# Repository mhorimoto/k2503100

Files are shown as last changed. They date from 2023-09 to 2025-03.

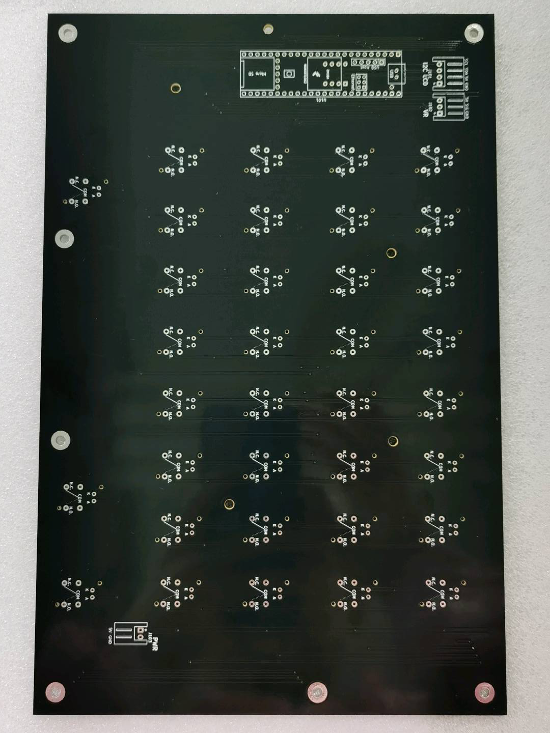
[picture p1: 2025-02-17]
DOCS/workarea/S-B67819ASP32サンプル写真確認/1.jpg

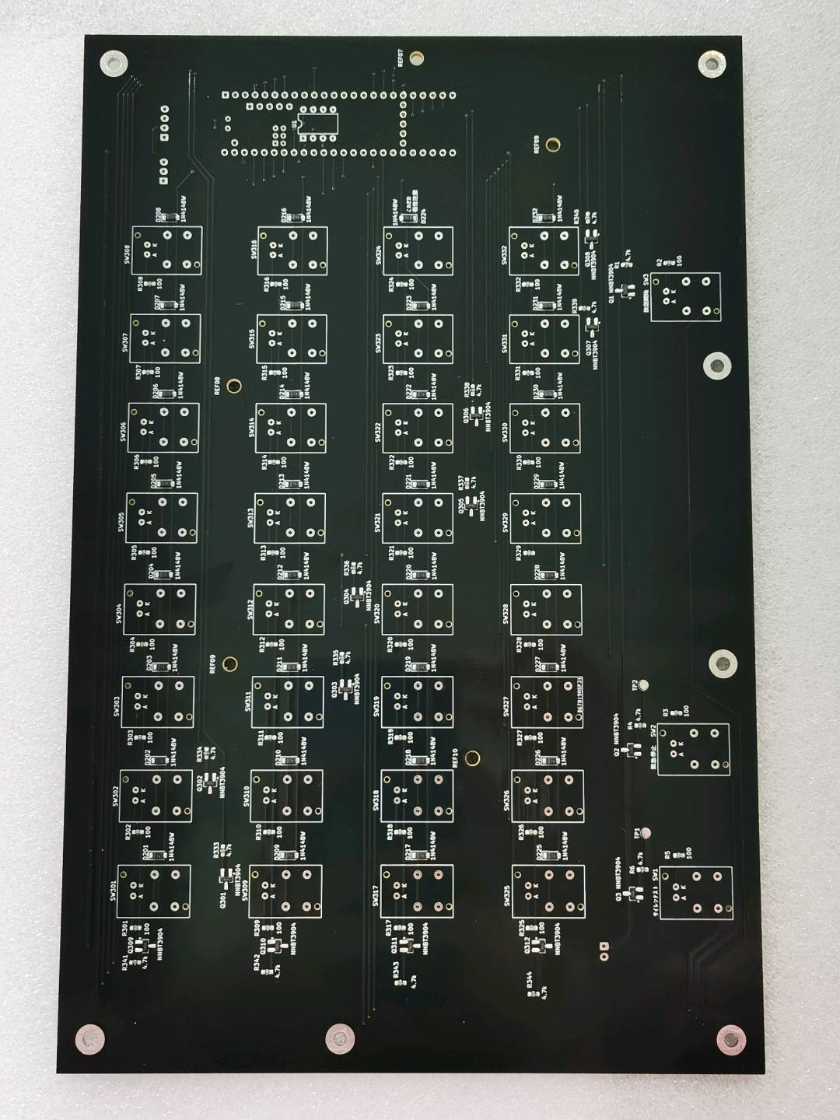
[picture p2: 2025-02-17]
DOCS/workarea/S-B67819ASP32サンプル写真確認/3.jpg

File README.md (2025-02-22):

# k2503100
リレーは使わない、SNMPだけ送信する＆Teensy4.1

## ディレクトリの説明

+ DOCS  
  設計に関する検討資料が含まれている。
+ KiCAD  
  KiCADによる回路設計の情報が含まれている。
  本装置はボタンスイッチを配置した基板が本体ケースの構成要素として大きな位置づけなので、
  本体ケースの製作に要する寸法図データもこのディレクトリに含めている。
+ PARTS_SPEC  
  製作に使用した部品の個別の仕様書やカタログが含まれている。
+ main  
  プログラムのソースコードが収められている。
  コンパイルなどはplatformIOを用いている。
+ snmp-manager  
  snmp-managerライブラリを用いた試験プログラムが収められている。普通は使わない。
+ snmp-test  
  snmp動作のテストプログラムが収められている。普通は使わない。
+ snmplib  
  snmpsetの動作確認用のプログラムが収められている。普通は使わない。
+ tools
  Ubuntu(Debian)系でplatformIOを使うときのudevruleファイルが収められている。

# CAUTION VERY IMPORTANT 重要な注意

PCB Revision 1.20まではLEDドライブ用のTrのフットパターンを間違えているので使わないように。

Don't use the wrong foot pattern of Tr for LED drive until PCB Revision 1.20.

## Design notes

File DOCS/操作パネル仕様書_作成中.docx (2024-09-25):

機器仕様書(暫定)

操作パネル

# 1. 適用

本仕様書は操作パネル（型式をここに入れる）に適用します。

# 2. 概要

本機は、事務机などのデスクの上に設置するBOX型の装置です。

BOXにはボタンが搭載されており、ボタンを押下することにより、FM告知放送システム、

メール発報システムを自動で起動させることが出来ます。

# 3. 特徴

本機は以下の特長を持ちます。

・ボタンを35個搭載しており、それぞれ、地区ボタン（32地区）、テストサイレンボタン、

強制終了ボタン、放送開始ボタンを有しております。

・選択されたボタンは選択されたことが分かるように点灯します。

・地区ボタンを選択し、放送開始ボタンを押下することにより、その地区に対応したFM告知放

送と、消防関係者へのメールを発報することが出来ます。

・地区選択を誤った場合、再度ボタンを押下することにより、選択解除が出来ます。

・地区選択後、放送開始ボタンを1分間押下されなかった場合、全ての条件を解除します。

（誤放送防止）

・放送開始後に、誤放送に気付いた場合、強制終了ボタンを押す事により、放送を中止すること

が出来ます。

# 4. 機器仕様

## 性能（暫定）

CPU | Intel® Xeon® E-2124（3.3GHz 4コア）
メモリ | 16GB DDR4 UDIMM
ストレージ | 2TB ホットプラグ3.5型SAS HDD×2（同一HDD 2基でRAID1構成）
LANインターフェース | RJ-45コネクタ×4（Ethernet® 1Gb 4ポート）
通信方式 | SNMP
電源 | AC100V (50/60 Hz)
消費電力 | 70VA
サイズ | W:434×D:424×H:44 mm（突起部除く）

## 環境条件（暫定）

本機は屋内専用です。動作環境は以下の通りとなりますが、日光の直射・結露・腐食性環境・衝撃・連続的な振動等は避けてください。

温度 | 動作時 10～35℃
湿度 | 動作時 8～90%（結露しないこと）

# 5. 外形図（暫定）

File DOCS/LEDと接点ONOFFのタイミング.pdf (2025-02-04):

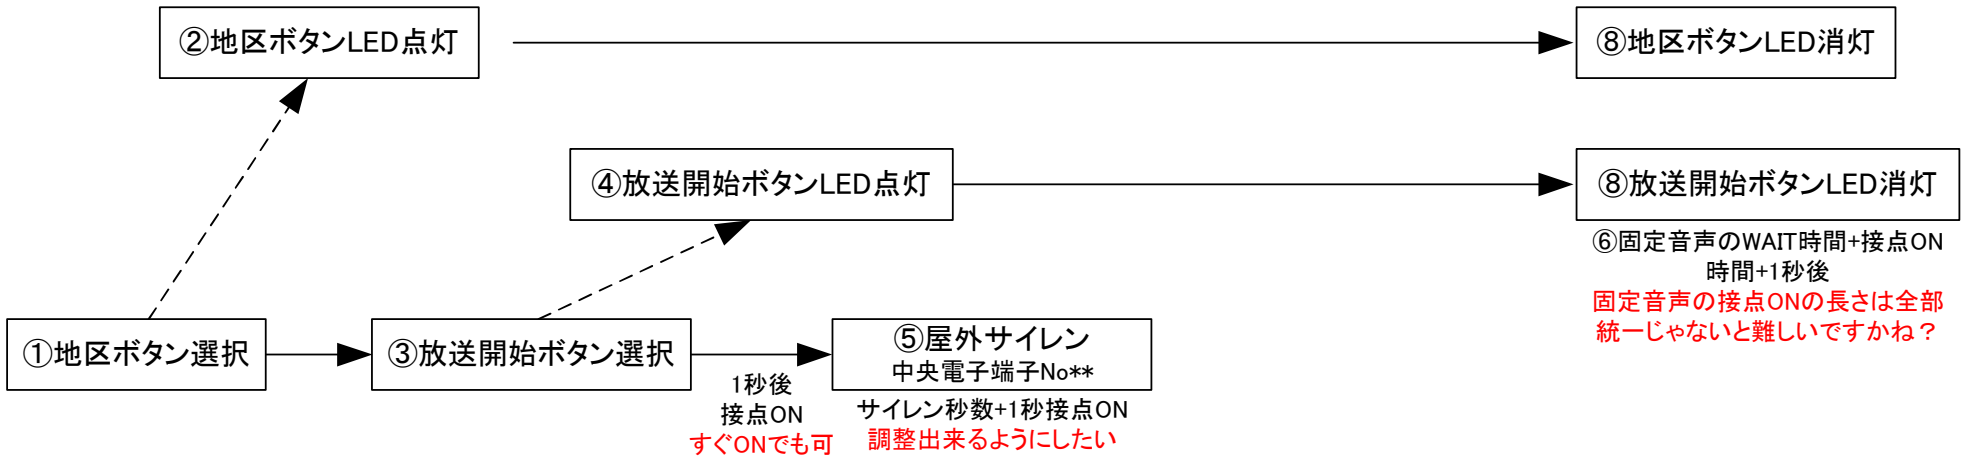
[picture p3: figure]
①地区ボタン選択; ③放送開始ボタン選択; ⑤屋外サイレン; 中央電子端子No**; サイレン秒数+1秒接点ON 調整出来るようにしたい; 1秒後 接点ON すぐONでも可; ②地区ボタンLED点灯; ④放送開始ボタンLED点灯; ⑧地区ボタンLED消灯; ⑧放送開始ボタンLED消灯; ⑥固定音声のWAIT時間+接点ON 時間+1秒後 固定音声の接点ONの長さは全部 統一じゃないと難しいですかね？

### ⑦メール発報

中央電子端子No**
接点3秒間ON
基本3秒で問題ないと思う
が、調整出来るようになって
いるとありがたいです

1秒+サイレン秒数+1秒後　接点ON
難しければ⑤と同時にONでも可

### ⑥固定音声ON

中央電子端子No**
地区名によって若干長さが変わる
接点ONの時間を現地で調整出来
るようにしたい

1秒+サイレン秒数+1秒後　接点ON
難しければ⑤と同時にONでも可

※当初はすぐに接点ONにする感じでしたが、
強制終了の対象に出来ると思い希望を書きました

# LED、接点ONのタイミングと時間

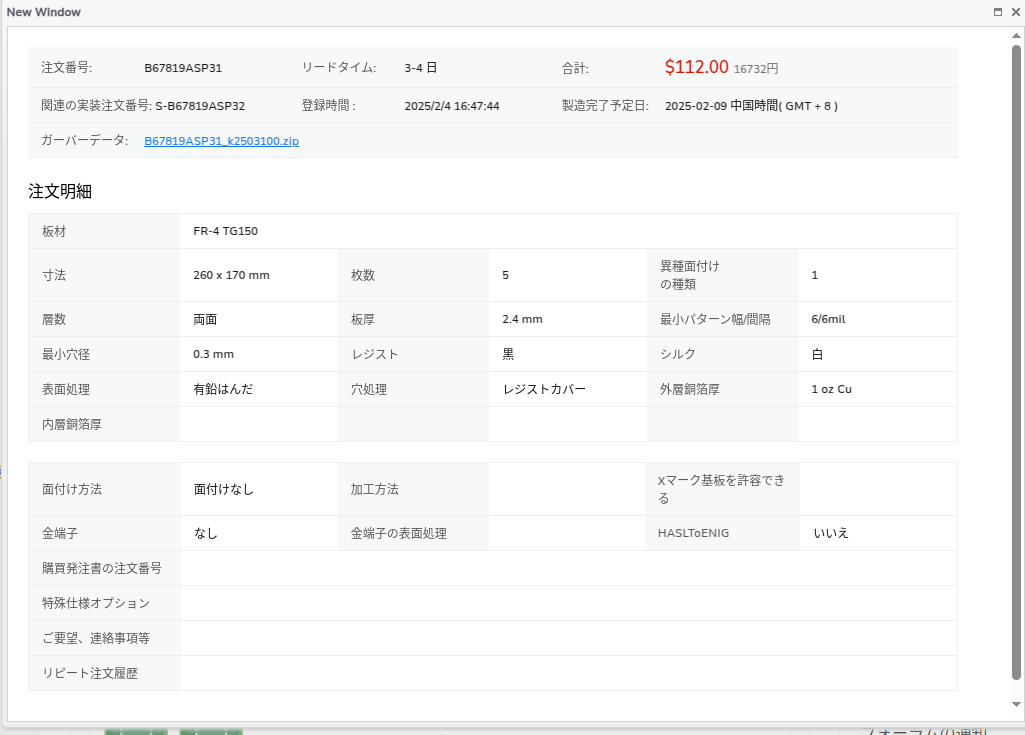
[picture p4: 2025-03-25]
KiCAD/k2503100/GOUT/Screenshot_PCBgogo.png

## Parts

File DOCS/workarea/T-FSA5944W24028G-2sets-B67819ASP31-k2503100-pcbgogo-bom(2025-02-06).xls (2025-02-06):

PCBGOGO Quotation, Order No.:
Item # | *Designator | *Qty | *Mfg Part # | Description / Value | *Package/Footprint | Your Instructions / Notes | *Delivery Time | *Actual Purchase Mfg Part # | *PCBGOGO Note | 客先確認
1 | R2,R3,R5,R301,R302,R303,R304,R305,R306,R307,R308,R309,R310,R311,R312,R313,R314,R315,R316,R317,R318,R319,R320,R321,R322,R323,R324,R325,R326,R327,R328,R329,R330,R331,R332 | 35 |  | 100『 』Resistor, US symbol | Resistor_SMD:R_0603_1608Metric_Pad0.98x0.95mm_HandSolder | ~ | ８日 | RC0603FR-07100RL |  | confirm OK
2 | R1,R4,R6,R333,R334,R335,R336,R337,R338,R339,R340,R341,R342,R343,R344 | 15 |  | 4.7k『 』Resistor, US symbol | Resistor_SMD:R_0603_1608Metric_Pad0.98x0.95mm_HandSolder | ~ | ８日 | RC0603FR-074K7L |  | confirm OK
3 | D201,D202,D203,D204,D205,D206,D207,D208,D209,D210,D211,D212,D213,D214,D215,D216,D217,D218,D219,D220,D221,D222,D223,D224,D225,D226,D227,D228,D229,D230,D231,D232 | 32 |  | 1N4148W『 』75V 0.15A Fast Switching Diode, SOD-123 | Diode_SMD:D_SOD-123 | https://www.vishay.com/docs/85748/1n4148w.pdf | ８日 | 1N4148W | The part we will supply is 1N4148W made by HXY MOSFET(华轩阳电子)，package: SOD-123 OK？ | HXY MOSFET 1N4148W is OK (https://www.lcsc.com/product-detail/Switching-Diode_HXY-MOSFET-1N4148W_C5345962.html)
4 | Q1,Q2,Q3,Q301,Q302,Q303,Q304,Q305,Q306,Q307,Q308,Q309,Q310,Q311,Q312 | 15 |  | NNBT3904『 』0.2A Ic, 40V Vce, Small Signal NPN Transistor | Package_TO_SOT_SMD:SOT-23_Handsoldering | https://akizukidenshi.com/goodsaffix/2N3904_MMBT3904_PZT3904.pdf | ８日 | MMBT3904 | The part we will supply is MMBT3904 made by HOTTECH，package: SOT-23 OK？ | HOTTECH MMBT3904 is OK (https://www.lcsc.com/product-detail/Bipolar-Transistors-BJT_Guangdong-Hottech-MMBT3904_C181119.html)
客户BOM中没有型号列，推荐了*Actual Purchase Mfg Part # *PCBWay Note请确认；麻烦客户下次提供有型号列和品牌列的BOM表

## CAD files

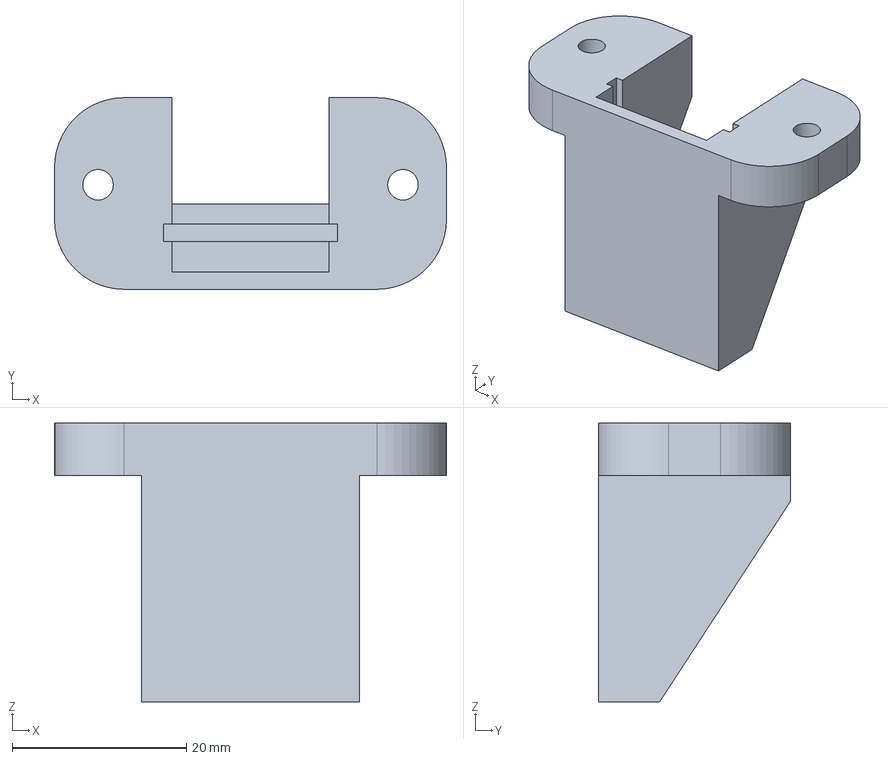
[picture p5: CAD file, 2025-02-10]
PARTS_SPEC/NIC-Adapter2-3views.FCStd
45.0 x 22.0 x 32.0 mm

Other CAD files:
PARTS_SPEC/NIC-Adapter2.FCStd
PARTS_SPEC/NIC-Adapter2.stl

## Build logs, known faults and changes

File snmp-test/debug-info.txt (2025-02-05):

14:41:39.178724 IP 192.168.42.32.snmp > atom3.55336:  C="private" GetResponse(36)  E:2589.1.2.2.2.6.1.5.112=1
	0x0000:  4500 0052 43da 0000 4011 612d c0a8 2a20  E..RC...@.a-..*.
	0x0010:  c0a8 2a23 00a1 d828 003e a3b5 3082 0032  ..*#...(.>..0..2
	0x0020:  0201 0004 0770 7269 7661 7465 a224 0204  .....private.$..
	0x0030:  0cf1 3aff 0201 0002 0100 3016 3014 060f  ..:.......0.0...
	0x0040:  2b06 0104 0194 1d01 0202 0206 0105 7002  +.............p.
	0x0050:  0101     
	
	3082 0032 0201 0004 0770 7269 7661 7465 a224 0204 0cf1 3aff 0201 0002 0100 3016 3014 060f 2b06 0104 0194 1d01 0202 0206 0105 7002 0101
	30 2F02 0100 0407 7072 6976 6174 65A3 2102 0101 0201 0002 0100 3000 1500 130F 2B06 0104 0194 1D01 0202 0206 0105 7002 0101
	
	Packet data: 0x30 0x2F 0x2 0x1 0x0 0x4 0x7 0x70 0x72 0x69 0x76 0x61 0x74 0x65 0xA3 0x21 0x2 0x1 0x1 0x2 0x1 0x0 0x2 0x1 0x0 0x30 0x0 0x15 0x0 0x13 0xF 0x2B 0x6 0x1 0x4 0x1 0x94 0x1D 0x1 0x2 0x2 0x2 0x6 0x1 0x5 0x70 0x2 0x1 0x1 
Packet size=49
Bytes sent: 49

15:30:58.779392 IP 192.168.42.35.37439 > 192.168.42.32.161:  C="private" SetRequest(36)  .1.3.6.1.4.1.2589.1.2.2.2.6.1.5.112=1
	0x0000:  4500 0050 26a8 4000 4011 3e61 c0a8 2a23  E..P&.@.@.>a..*#
	0x0010:  c0a8 2a20 923f 00a1 003c d5e1 3032 0201  ..*..?...<..02..
	0x0020:  0004 0770 7269 7661 7465 a324 0204 4ada  ...private.$..J.
	0x0030:  8966 0201 0002 0100 3016 3014 060f 2b06  .f......0.0...+.
	0x0040:  0104 0194 1d01 0202 0206 0105 7002 0101
	
3032 0201 0004 0770 7269 7661 7465 a324 0204 4ada 8966 0201 0002 0100 3016 3014 060f 2b06 0104 0194 1d01 0202 0206 0105 7002 0101 ==50bytes success
3082 0201 0004 0770 7269 7661 7465 A300 0204 2BB9 5130 0201 0002 0100 3010 300E 060F 2B06 0104 0194 1D01 0202 0206 0105 7002 0101
3082 0032 0201 0004 0770 7269 7661 7465 A300 0204 2BB9 5130 0201 0002 0100 3010 300E 060F 2B06 0104 0194 1D01 0202 0206 0105 7002 0101 AA
3032 0201 0004 0770 7269 7661 7465 A324 0204 42CE 0C1F 0201 0002 0100 3010 300E 060F 2B06 0104 0194 1D01 0202 0206 0105 7002 0100  BB
3032 0201 0004 0770 7269 7661 7465 A324 0204 ED3D 4074 0201 0002 0100 3016 3014 060F 2B06 0104 0194 1D01 0202 0206 0105 7002 0100  CC success
3032 0201 0004 0770 7269 7661 7465 A324 0204 FB5E B901 0201 0002 0100 3016 3014 060E 2B06 0104 0194 1D01 0202 0206 0105 7002 0101  -8 fail

Packet data: 3082 0032 0201 0004 0770 7269 7661 7465 A300 0204 2BB9 5130 0201 0002 0100 3010 300E 060F 2B06 0104 0194 1D01 0202 0206 0105 7002 0101 
Packet size=54
Bytes sent: 54

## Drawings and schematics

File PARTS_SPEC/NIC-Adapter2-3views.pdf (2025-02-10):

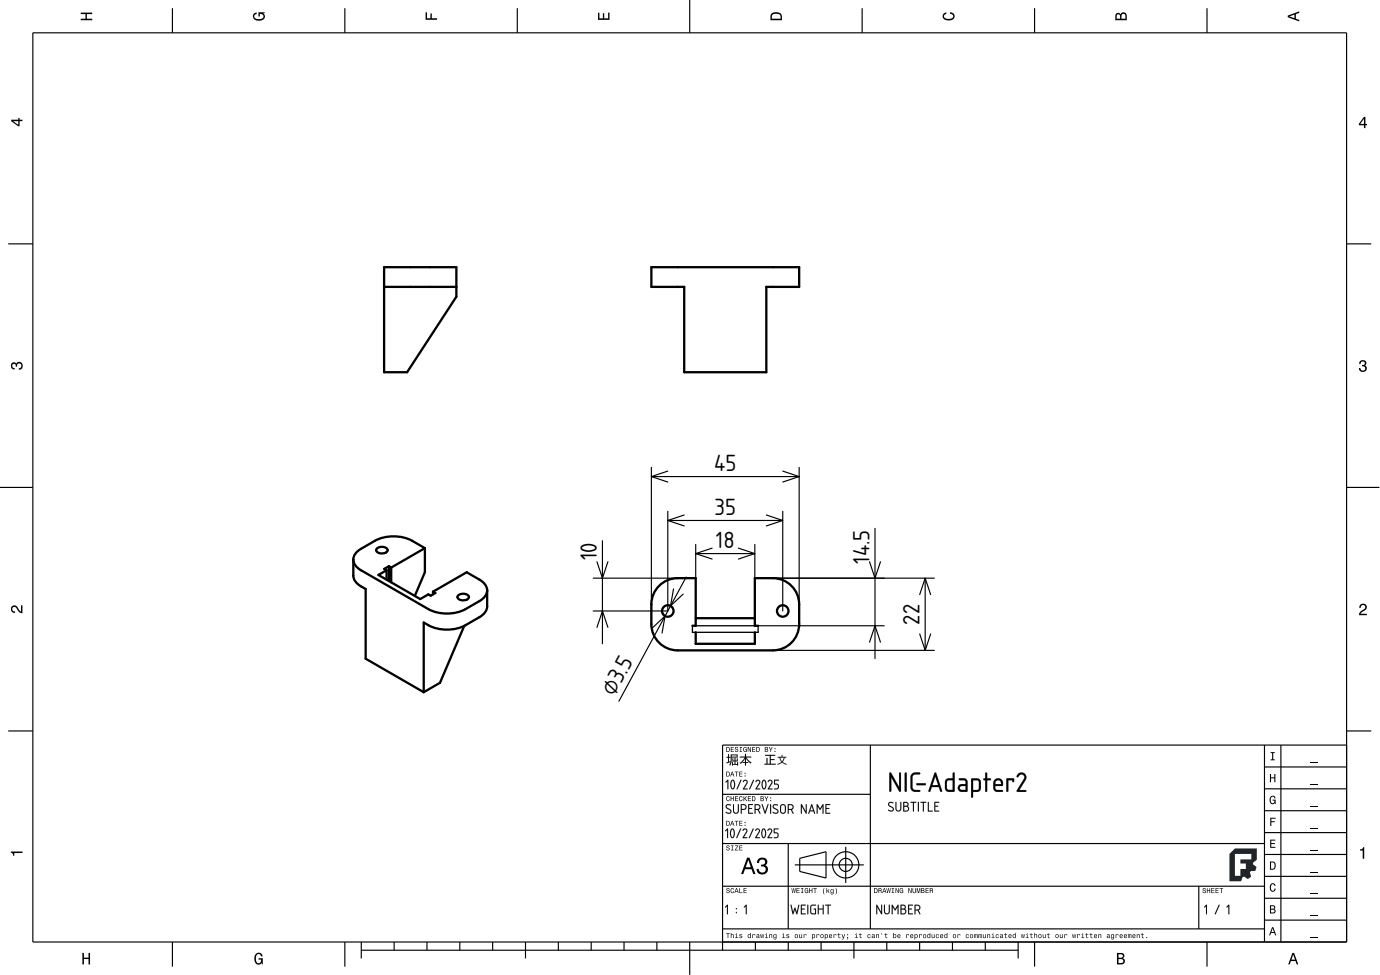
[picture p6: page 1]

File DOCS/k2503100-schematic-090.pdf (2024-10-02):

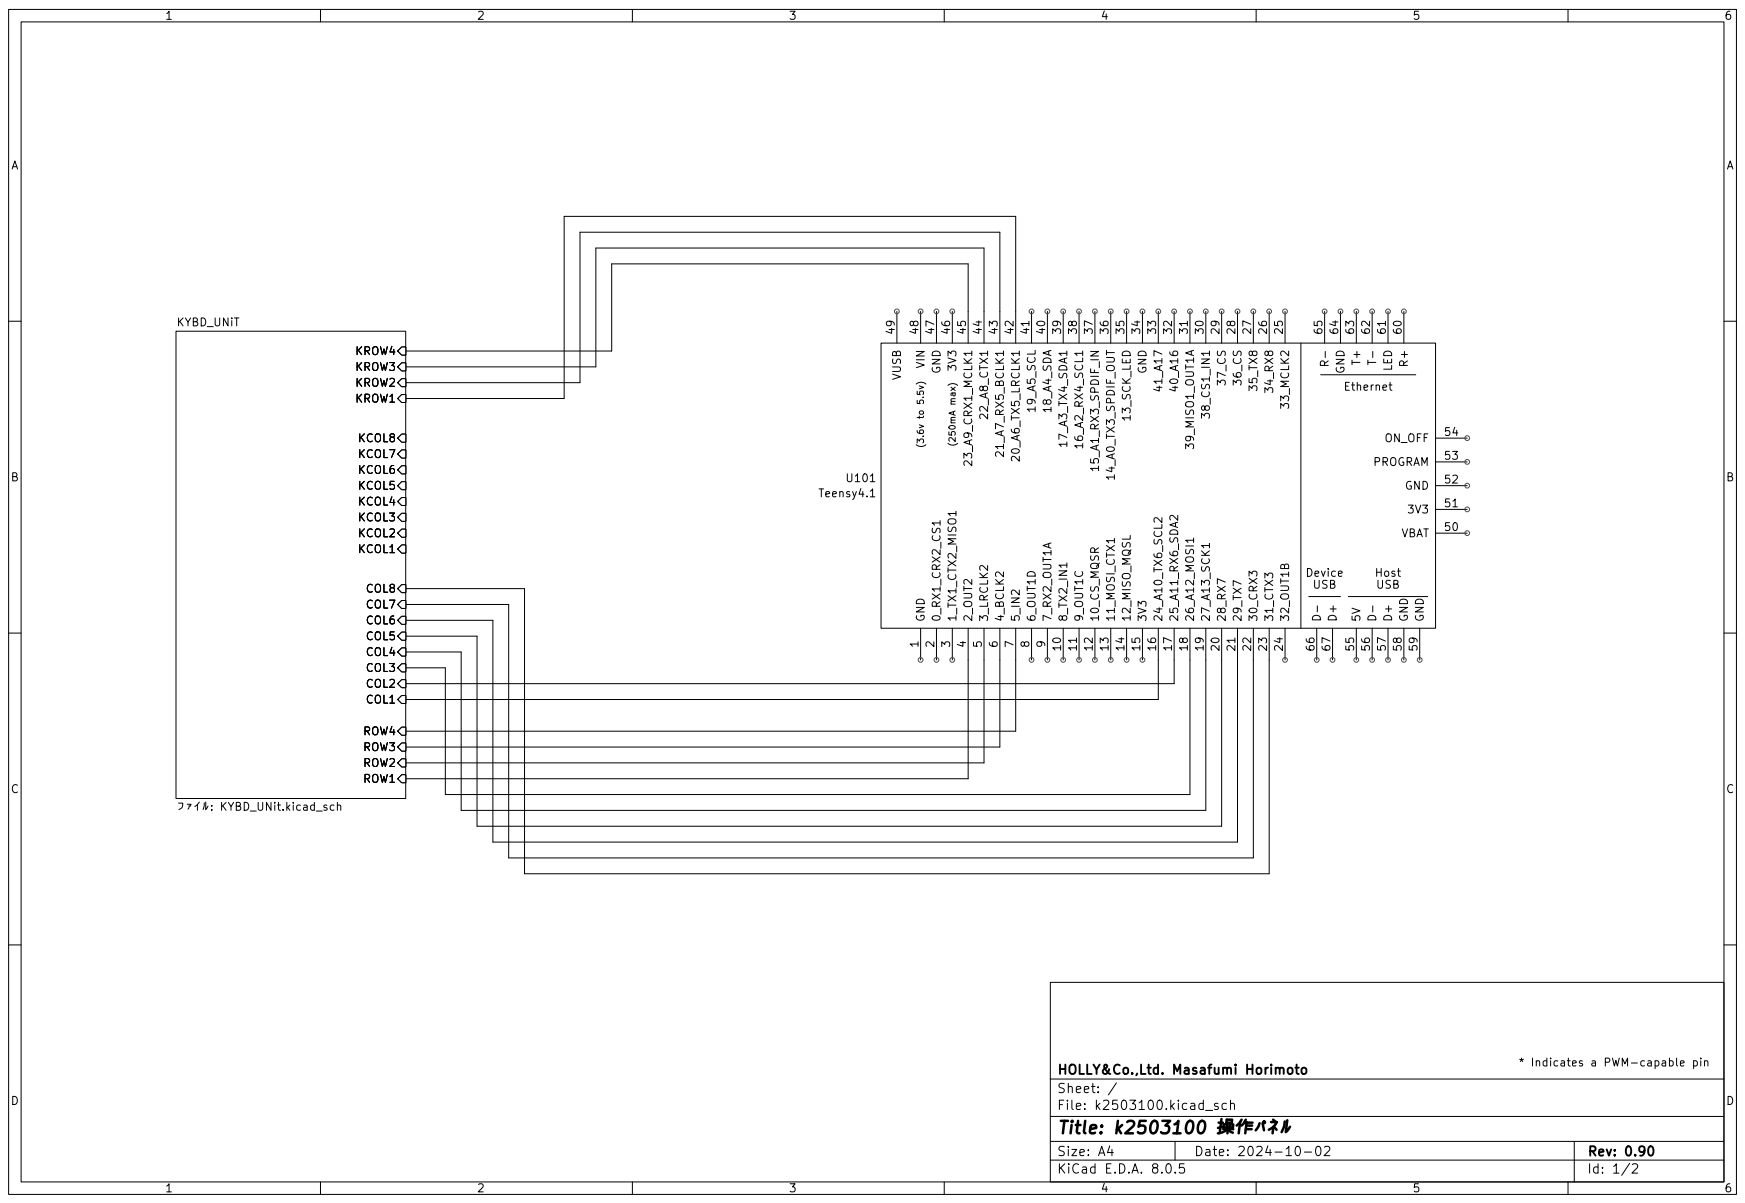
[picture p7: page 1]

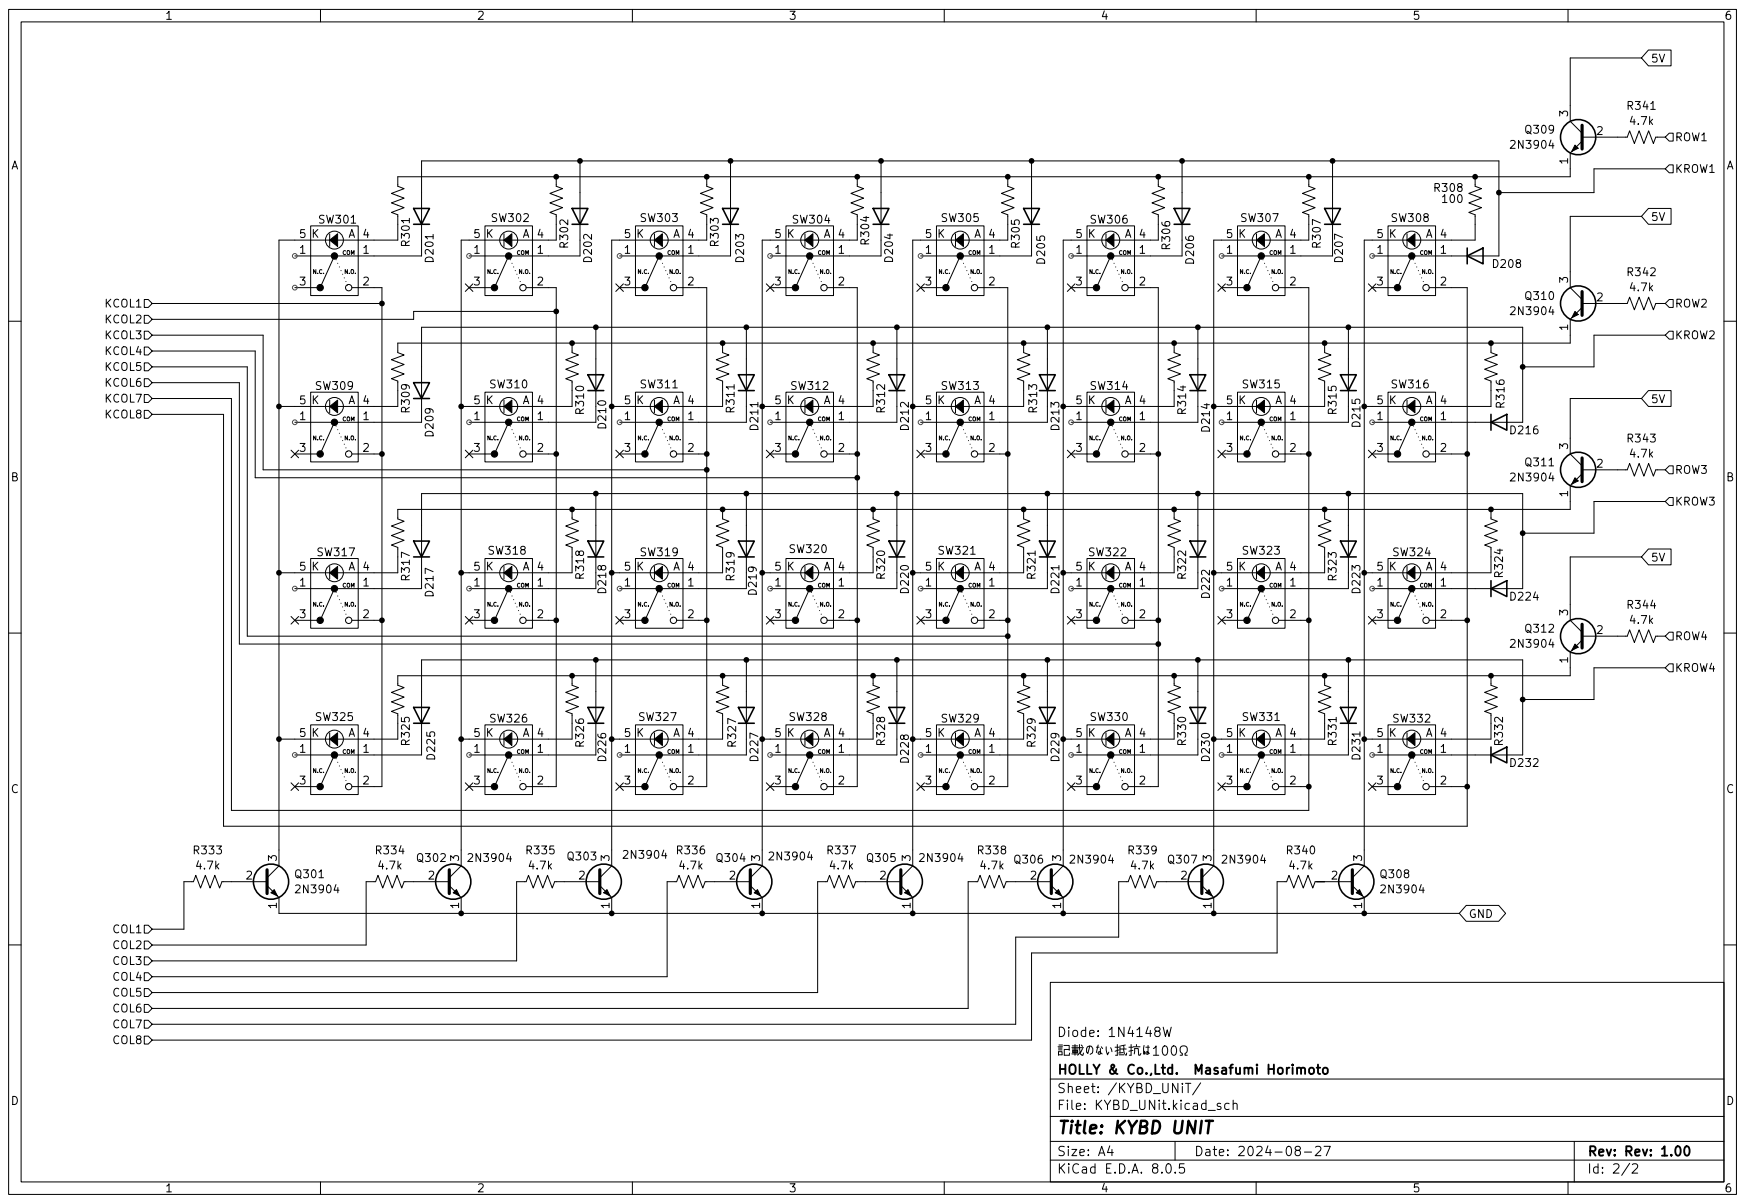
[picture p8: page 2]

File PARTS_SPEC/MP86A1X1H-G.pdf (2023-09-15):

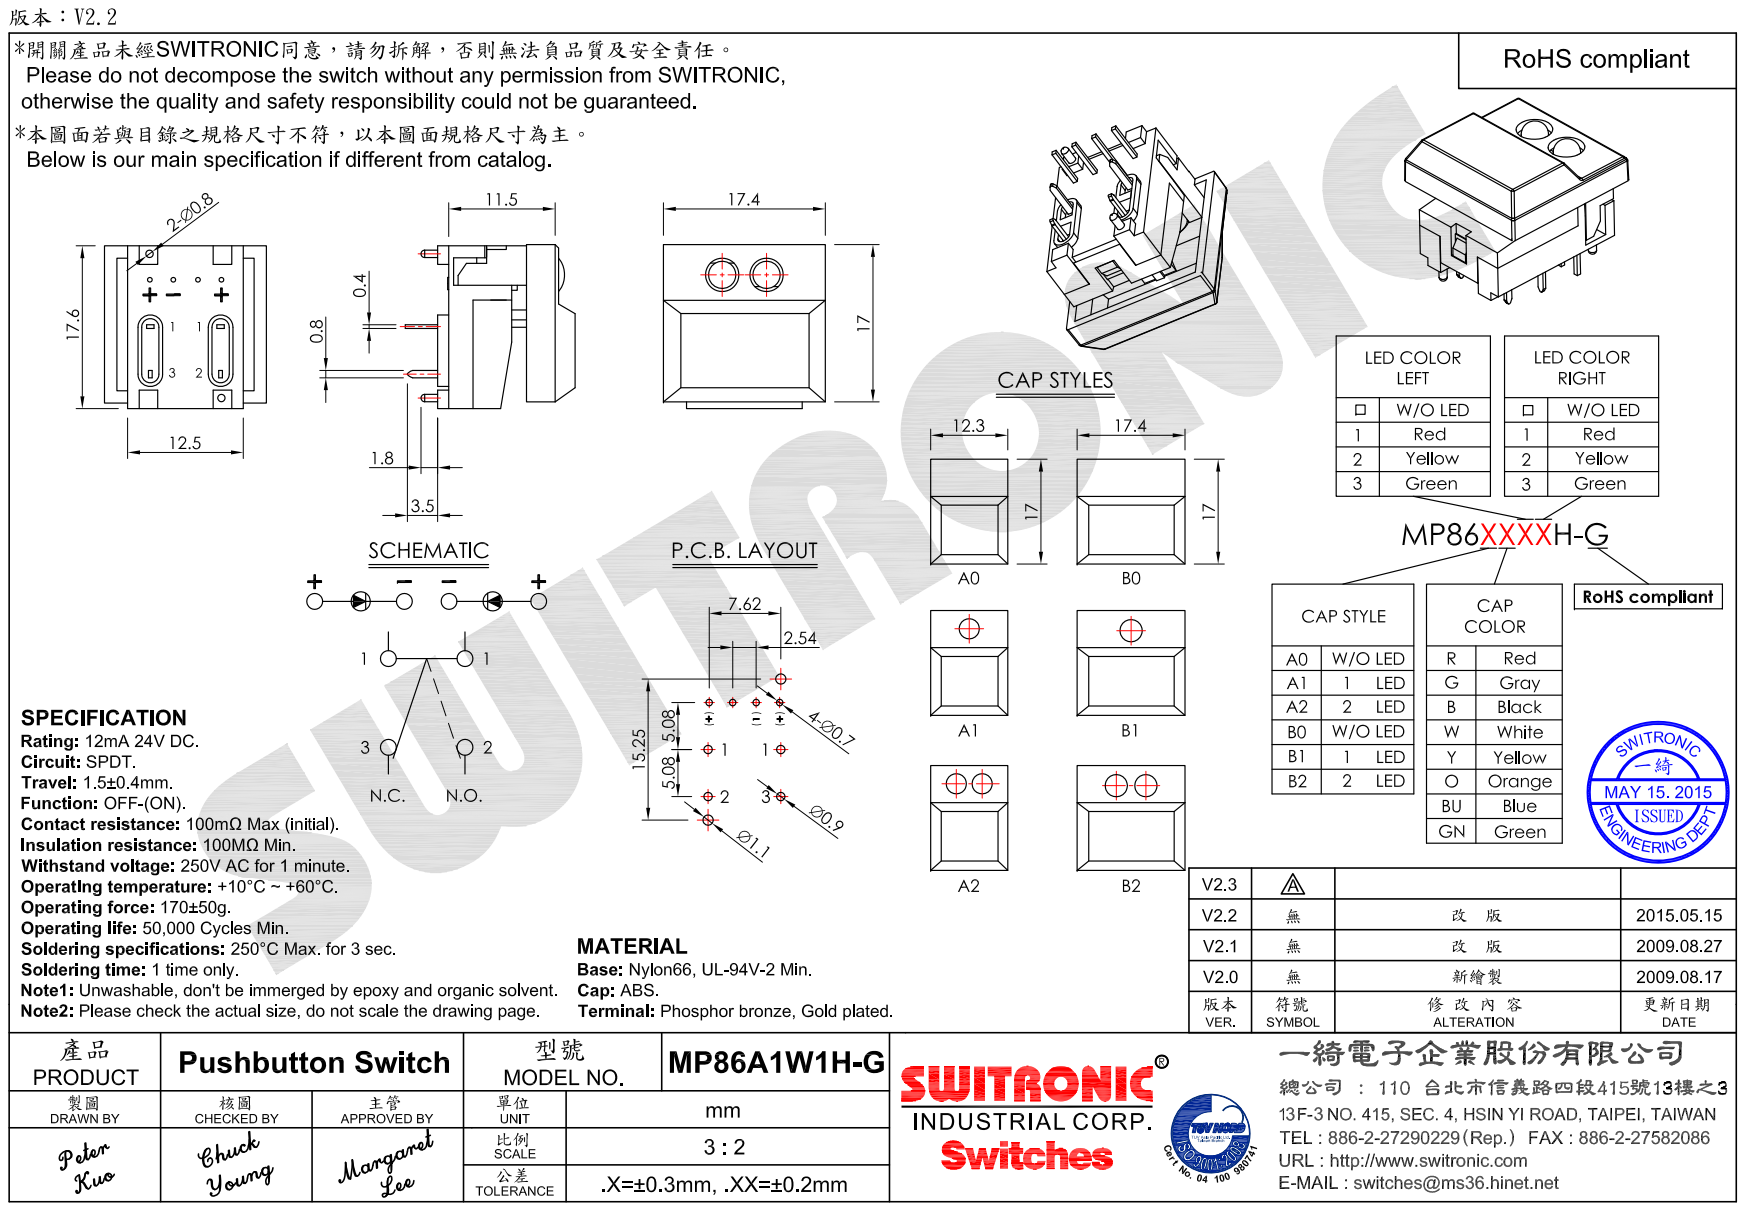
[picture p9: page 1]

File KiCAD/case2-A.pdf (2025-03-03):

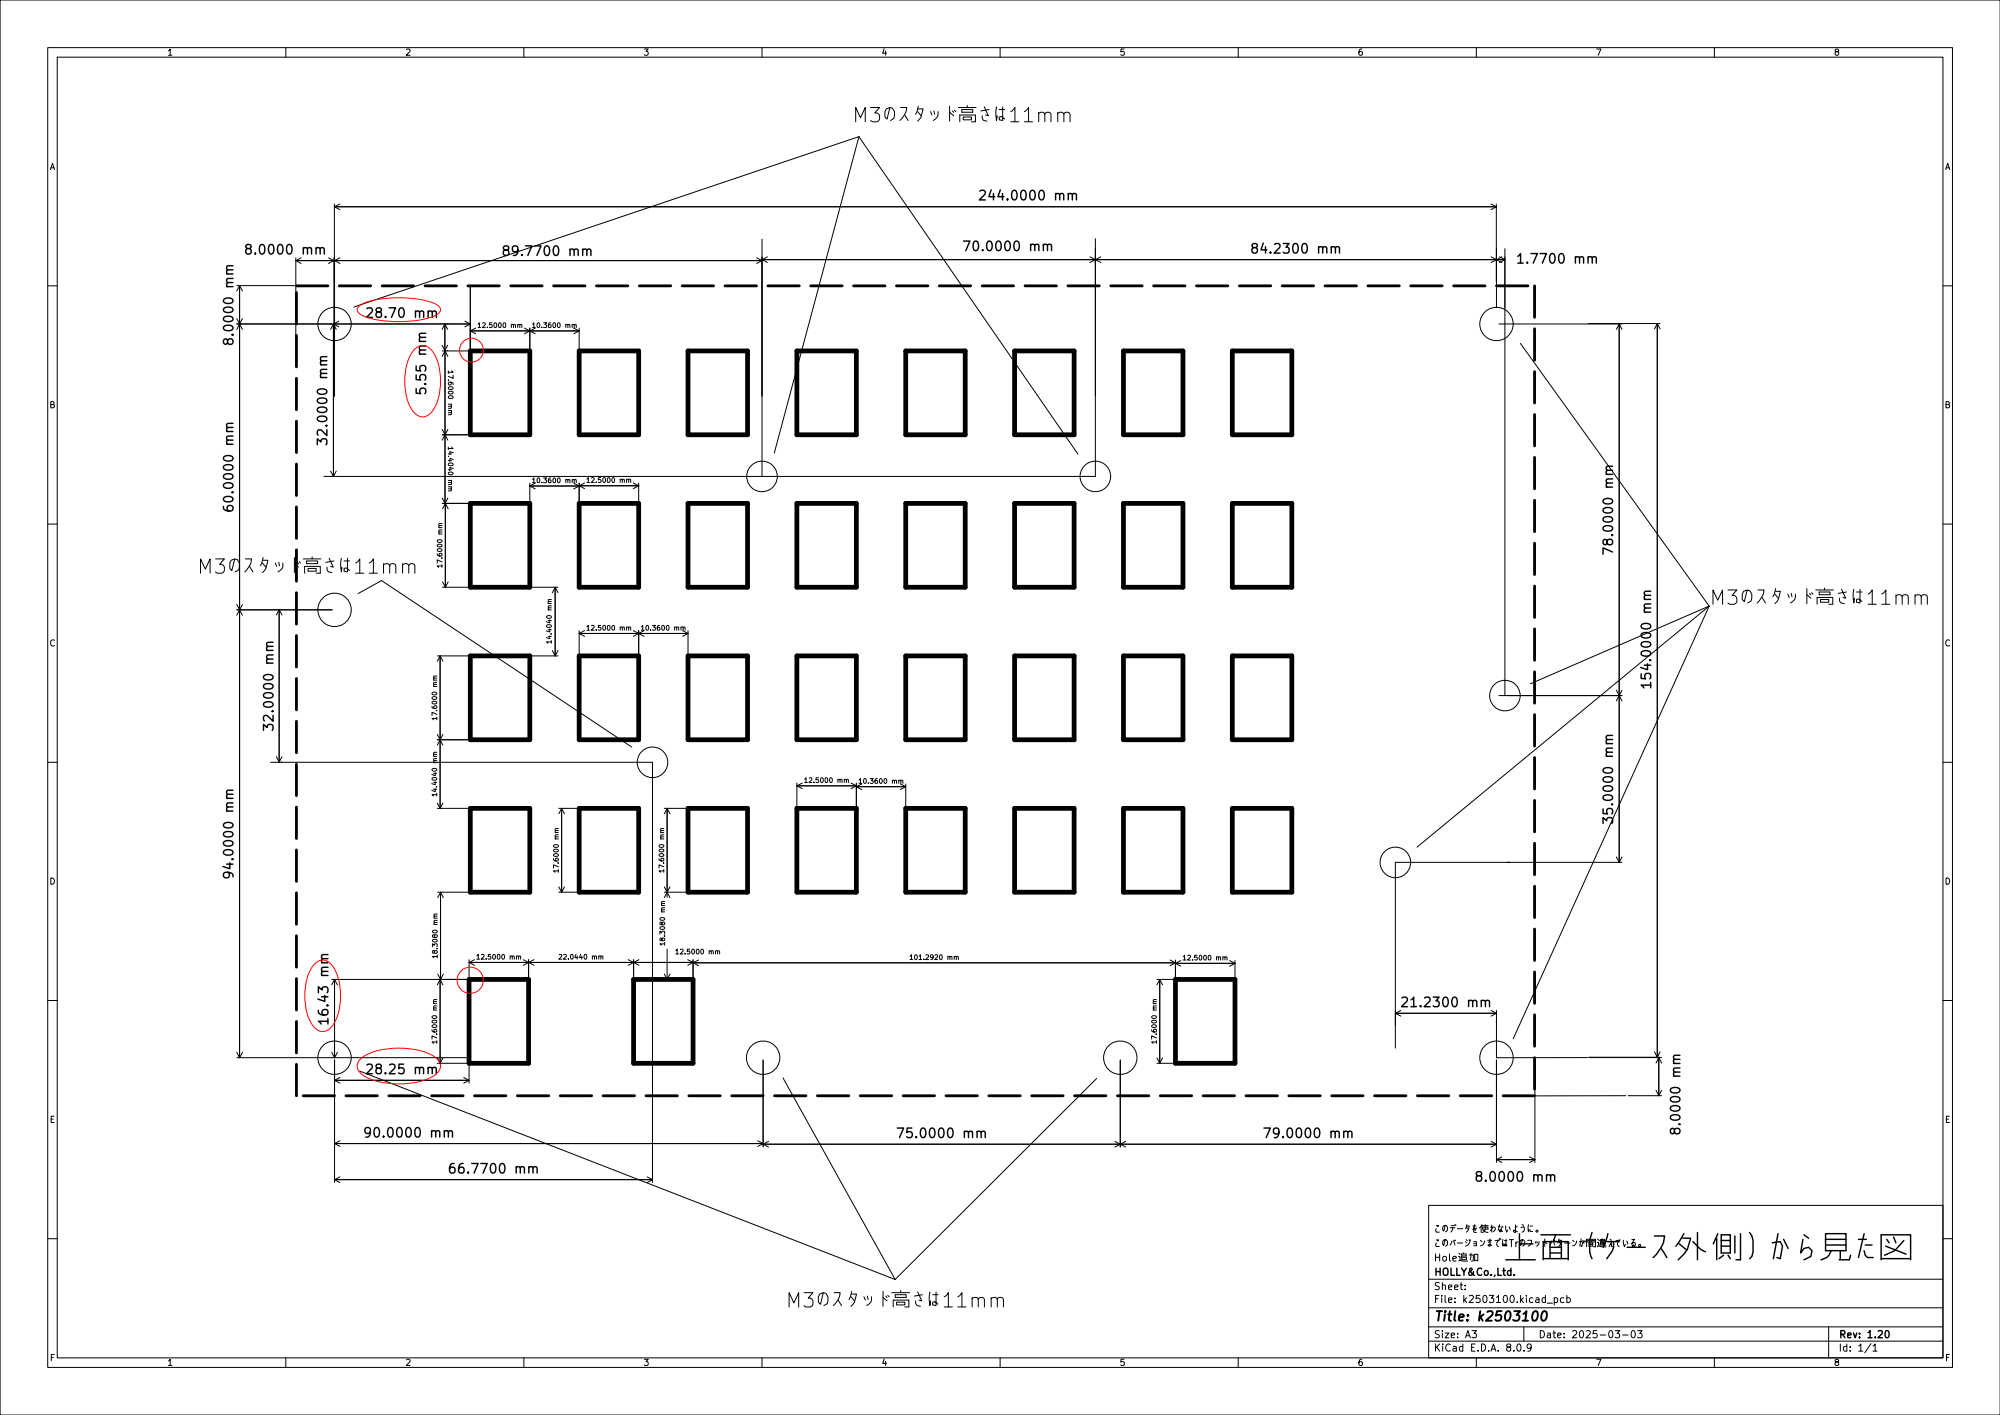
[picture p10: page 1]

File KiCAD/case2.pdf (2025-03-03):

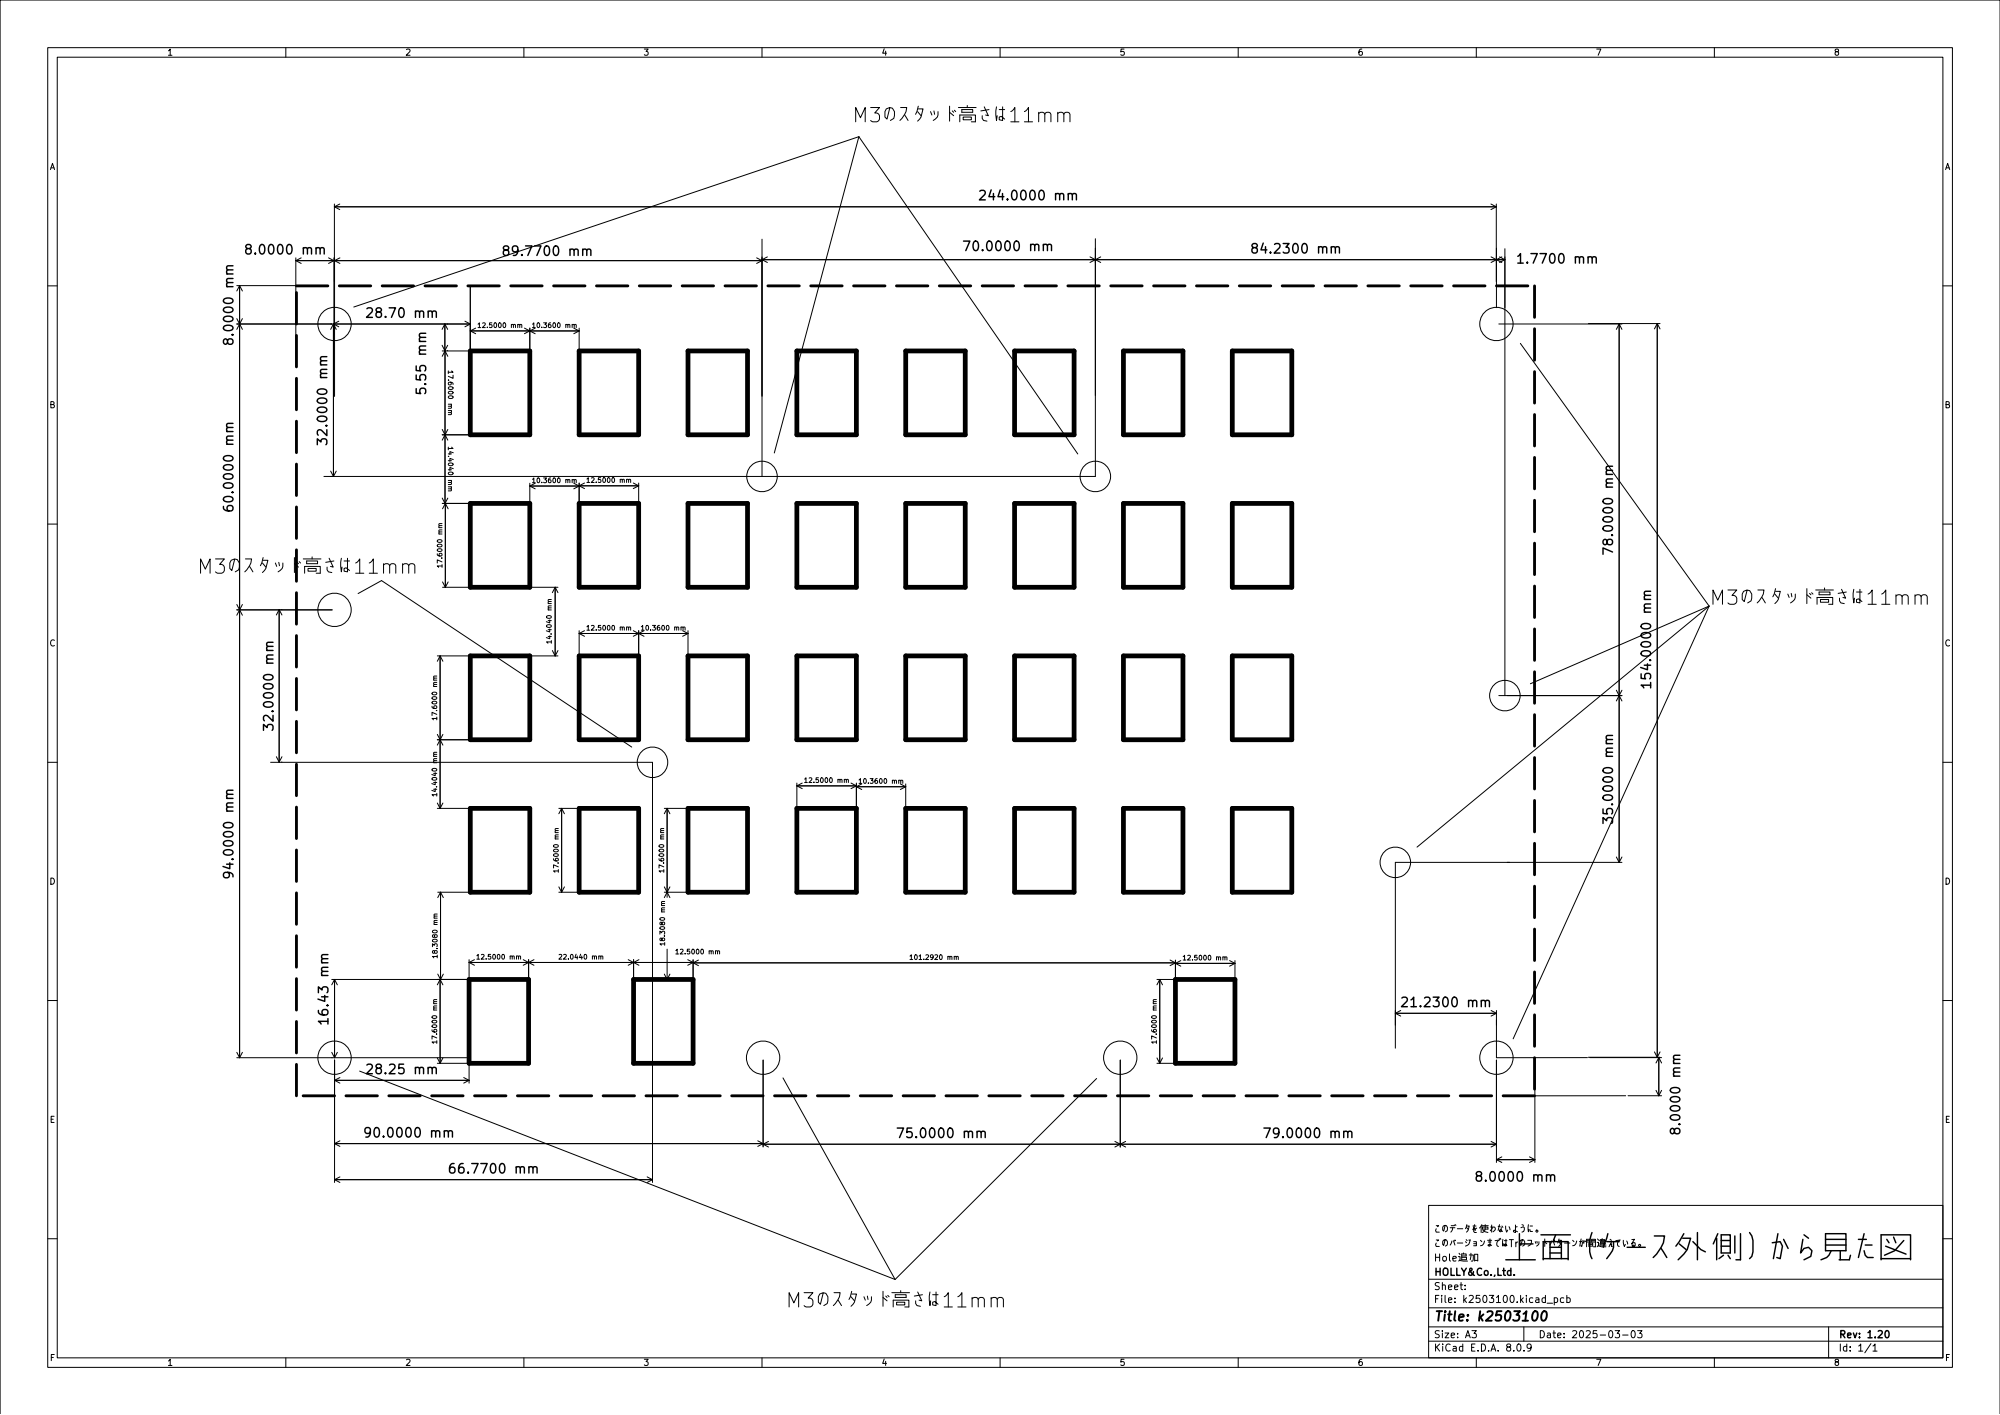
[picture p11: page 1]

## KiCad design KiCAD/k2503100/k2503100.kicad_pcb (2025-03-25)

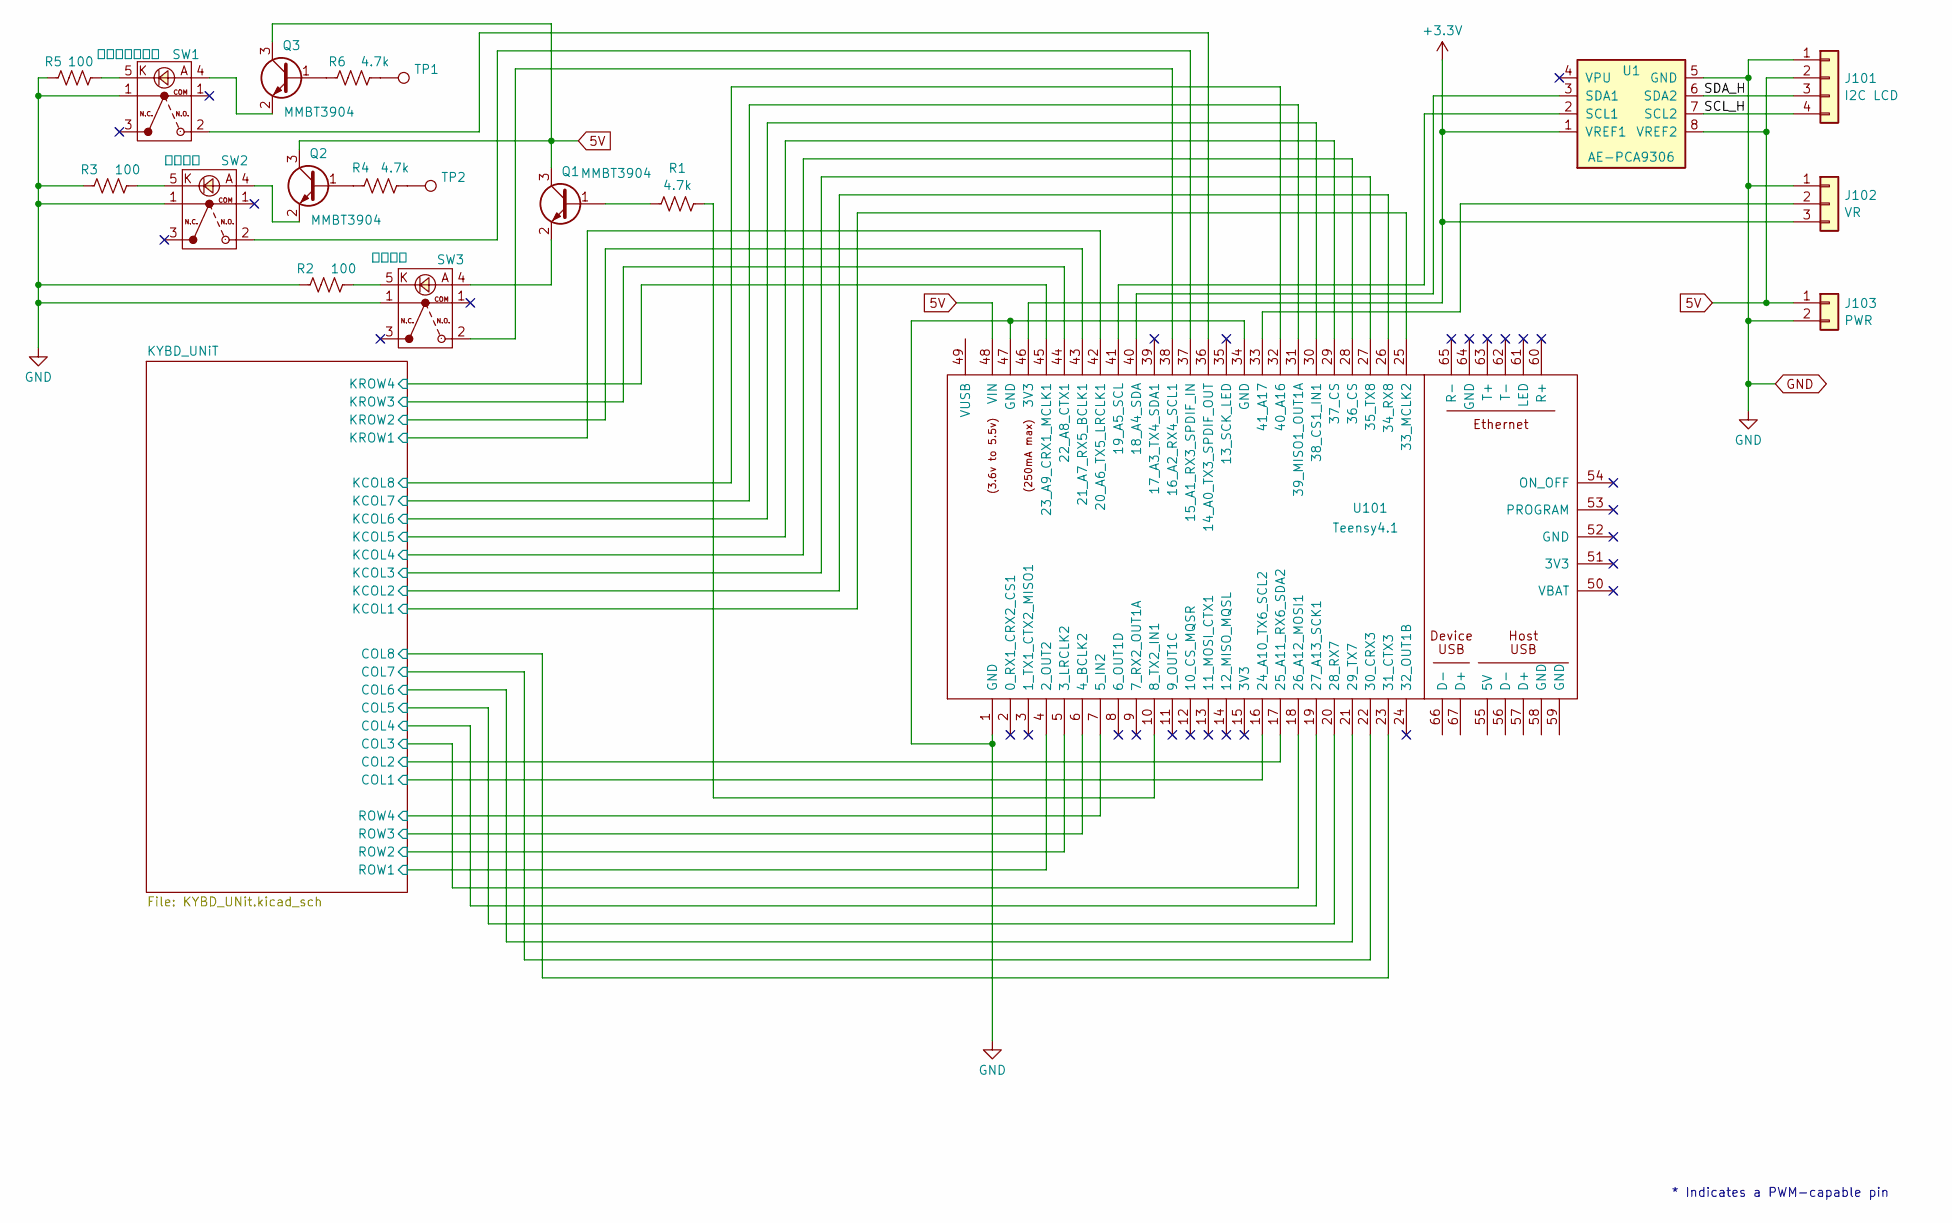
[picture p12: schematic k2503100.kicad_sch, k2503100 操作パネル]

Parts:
J101: I2C LCD; JST_XH_S4B-XH-A_1x04_P2.50mm_Horizontal
J102: VR; JST_XH_S3B-XH-A_1x03_P2.50mm_Horizontal
J103: PWR; JST_XH_S2B-XH-A_1x02_P2.50mm_Horizontal
Q1, Q2, Q3: MMBT3904; SOT-23
R1, R4, R6: 4.7k; R_0603_1608Metric_Pad0.98x0.95mm_HandSolder
R2, R3, R5: 100; R_0603_1608Metric_Pad0.98x0.95mm_HandSolder
SW1: サイレンテスト; MP86A1
SW2: 緊急停止; MP86A1
SW3: 放送開始; MP86A1
TP1, TP2: TestPoint; TestPoint_Pad_D2.0mm
U1: AE-PCA9306; DIP-8_W7.62mm
U101: Teensy4.1; Teensy41

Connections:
5V: J101.2, J103.1, Q1.3 (C), Q2.3 (C), Q3.3 (C), U1.8 (VREF2), U101.48 (VIN); also elsewhere on the board
+3.3V: J102.3, U1.1 (VREF1), U101.46 (3V3)
/KYBD_UNiT/COL1: U101.16 (24_A10_TX6_SCL2); also elsewhere on the board
/KYBD_UNiT/COL2: U101.17 (25_A11_RX6_SDA2); also elsewhere on the board
/KYBD_UNiT/COL3: U101.18 (26_A12_MOSI1); also elsewhere on the board
/KYBD_UNiT/COL4: U101.19 (27_A13_SCK1); also elsewhere on the board
/KYBD_UNiT/COL5: U101.20 (28_RX7); also elsewhere on the board
/KYBD_UNiT/COL6: U101.21 (29_TX7); also elsewhere on the board
/KYBD_UNiT/COL7: U101.22 (30_CRX3); also elsewhere on the board
/KYBD_UNiT/COL8: U101.23 (31_CTX3); also elsewhere on the board
/KYBD_UNiT/KCOL1: U101.25 (33_MCLK2); also elsewhere on the board
/KYBD_UNiT/KCOL2: U101.26 (34_RX8); also elsewhere on the board
/KYBD_UNiT/KCOL3: U101.27 (35_TX8); also elsewhere on the board
/KYBD_UNiT/KCOL4: U101.28 (36_CS); also elsewhere on the board
/KYBD_UNiT/KCOL5: U101.29 (37_CS); also elsewhere on the board
/KYBD_UNiT/KCOL6: U101.30 (38_CS1_IN1); also elsewhere on the board
/KYBD_UNiT/KCOL7: U101.31 (39_MISO1_OUT1A); also elsewhere on the board
/KYBD_UNiT/KCOL8: U101.32 (40_A16); also elsewhere on the board
/KYBD_UNiT/KROW1: U101.42 (20_A6_TX5_LRCLK1); also elsewhere on the board
/KYBD_UNiT/KROW2: U101.43 (21_A7_RX5_BCLK1); also elsewhere on the board
/KYBD_UNiT/KROW3: U101.44 (22_A8_CTX1); also elsewhere on the board
/KYBD_UNiT/KROW4: U101.45 (23_A9_CRX1_MCLK1); also elsewhere on the board
/KYBD_UNiT/ROW1: U101.4 (2_OUT2); also elsewhere on the board
/KYBD_UNiT/ROW2: U101.5 (3_LRCLK2); also elsewhere on the board
/KYBD_UNiT/ROW3: U101.6 (4_BCLK2); also elsewhere on the board
/KYBD_UNiT/ROW4: U101.7 (5_IN2); also elsewhere on the board
/SCL_H: J101.4, U1.7 (SCL2)
/SDA_H: J101.3, U1.6 (SDA2)
GND: J101.1, J102.1, J103.2, R2.2, R3.2, R5.2, SW1.1, SW2.1, SW3.1, U1.5 (GND), U101.1 (GND), U101.34 (GND), U101.47 (GND); also elsewhere on the board
unnamed: J102.2, U101.33 (41_A17)
unnamed: Q1.1 (B), R1.1
unnamed: Q1.2 (E), SW3.4
unnamed: Q2.1 (B), R4.1
unnamed: Q2.2 (E), SW2.4
unnamed: Q3.1 (B), R6.1
unnamed: Q3.2 (E), SW1.4
unnamed: R2.1, SW3.5
unnamed: R3.1, SW2.5
unnamed: R4.2, TP2.1
unnamed: R5.1, SW1.5
unnamed: R6.2, TP1.1
unnamed: U1.2 (SCL1), U101.41 (19_A5_SCL)
unnamed: U1.3 (SDA1), U101.40 (18_A4_SDA)
unnamed: R1.2, U101.10 (8_TX2_IN1)
unnamed: SW1.2, U101.36 (14_A0_TX3_SPDIF_OUT)
unnamed: SW2.2, U101.37 (15_A1_RX3_SPDIF_IN)
unnamed: SW3.2, U101.38 (16_A2_RX4_SCL1)

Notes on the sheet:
* Indicates a PWM-capable pin

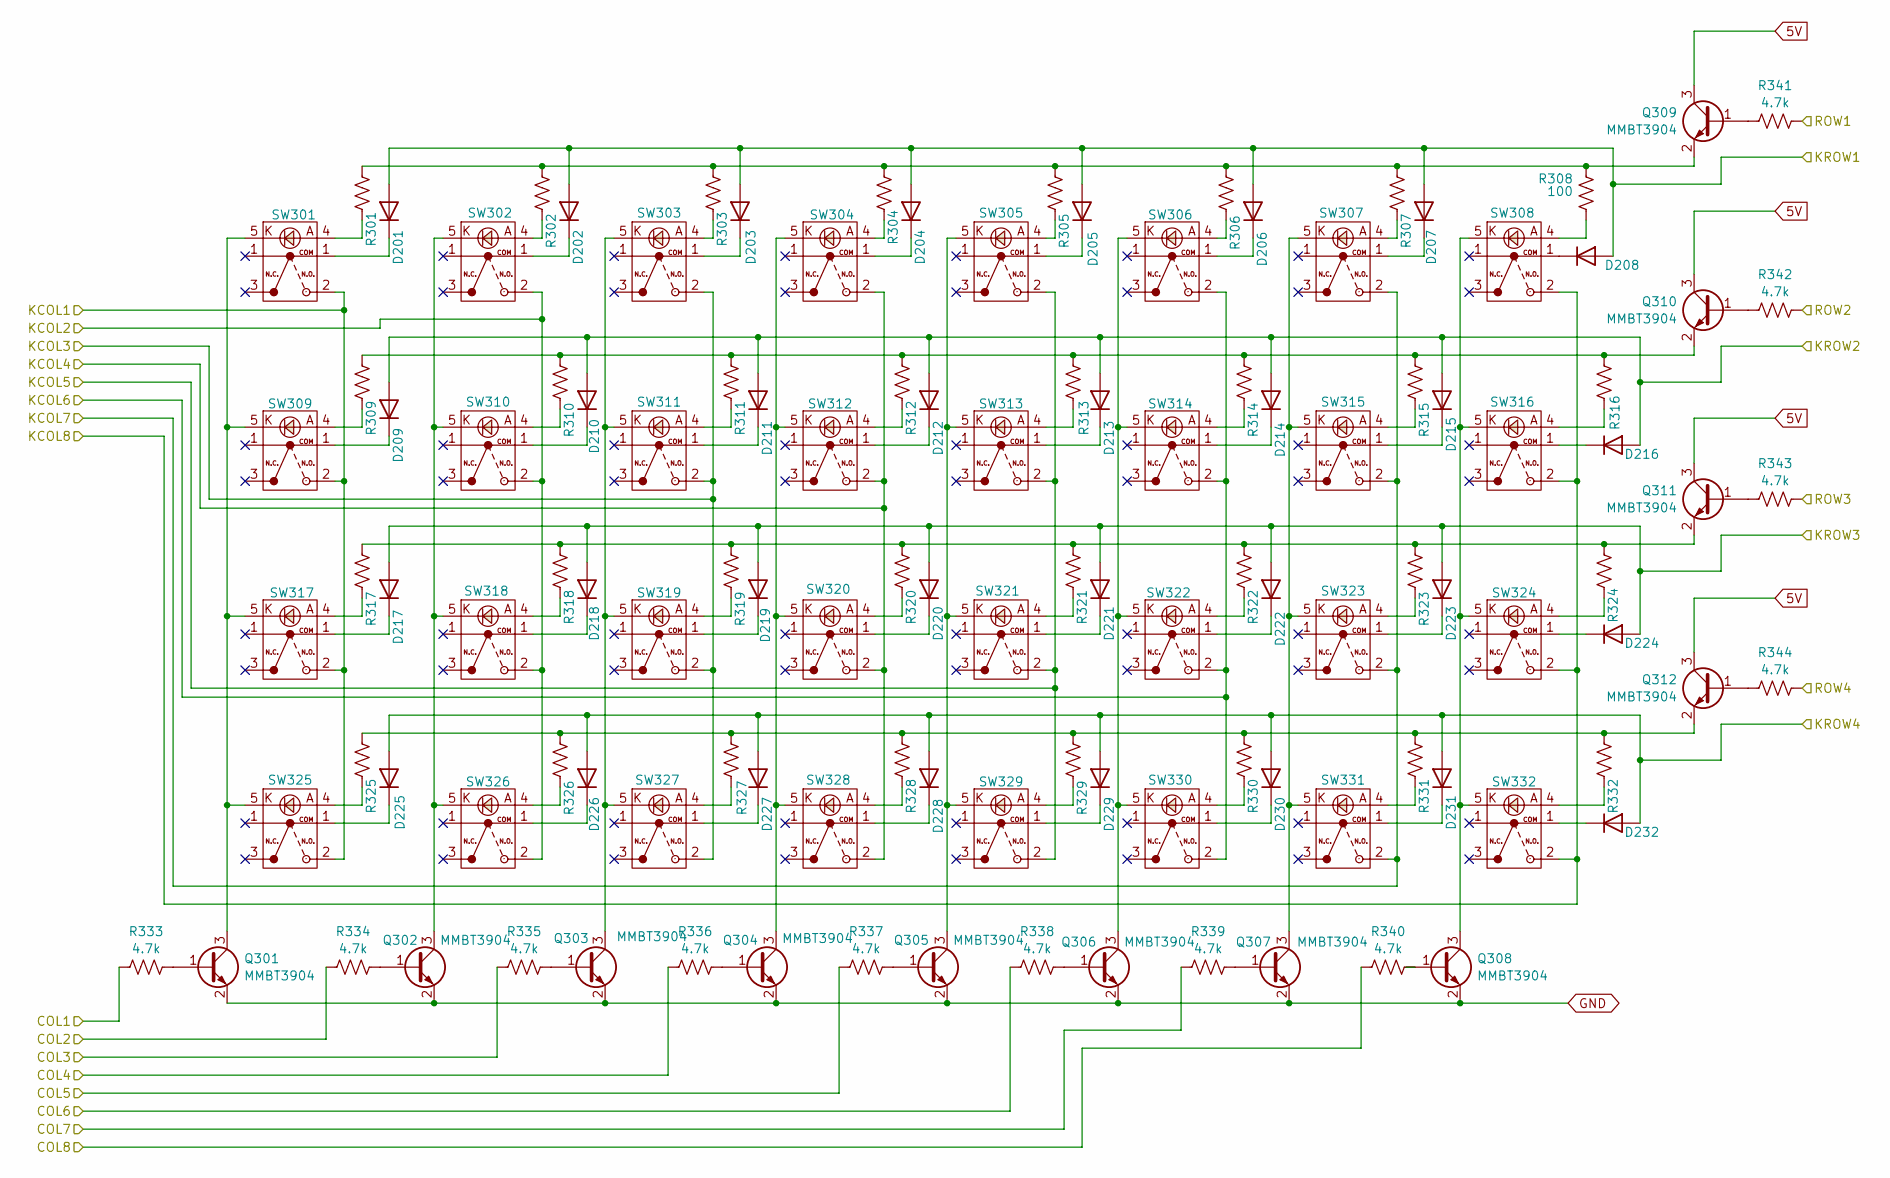
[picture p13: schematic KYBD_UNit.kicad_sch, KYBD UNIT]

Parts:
D201, D202, D203, D204, D205, D206, D207, D208, D209, D210, D211, D212, D213, D214, D215, D216, D217, D218, D219, D220, D221, D222, D223, D224, D225, D226, D227, D228, D229, D230, D231, D232: 1N4148W; D_SOD-123
Q301, Q302, Q303, Q304, Q305, Q306, Q307, Q308, Q309, Q310, Q311, Q312: MMBT3904; SOT-23
R301, R302, R303, R304, R305, R306, R307, R308, R309, R310, R311, R312, R313, R314, R315, R316, R317, R318, R319, R320, R321, R322, R323, R324, R325, R326, R327, R328, R329, R330, R331, R332: 100; R_0603_1608Metric_Pad0.98x0.95mm_HandSolder
R333, R334, R335, R336, R337, R338, R339, R340, R341, R342, R343, R344: 4.7k; R_0603_1608Metric_Pad0.98x0.95mm_HandSolder
SW301, SW302, SW303, SW304, SW305, SW306, SW307, SW308, SW309, SW310, SW311, SW312, SW313, SW314, SW315, SW316, SW317, SW318, SW319, SW320, SW321, SW322, SW323, SW324, SW325, SW326, SW327, SW328, SW329, SW330, SW331, SW332: MP86A1

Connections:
5V: Q309.3 (C), Q310.3 (C), Q311.3 (C), Q312.3 (C); also elsewhere on the board
/KYBD_UNiT/COL1: R333.1; also elsewhere on the board
/KYBD_UNiT/COL2: R334.1; also elsewhere on the board
/KYBD_UNiT/COL3: R335.1; also elsewhere on the board
/KYBD_UNiT/COL4: R336.1; also elsewhere on the board
/KYBD_UNiT/COL5: R337.1; also elsewhere on the board
/KYBD_UNiT/COL6: R338.1; also elsewhere on the board
/KYBD_UNiT/COL7: R339.1; also elsewhere on the board
/KYBD_UNiT/COL8: R340.1; also elsewhere on the board
/KYBD_UNiT/KCOL1: SW301.2, SW309.2, SW317.2, SW325.2; also elsewhere on the board
/KYBD_UNiT/KCOL2: SW302.2, SW310.2, SW318.2, SW326.2; also elsewhere on the board
/KYBD_UNiT/KCOL3: SW303.2, SW311.2, SW319.2, SW327.2; also elsewhere on the board
/KYBD_UNiT/KCOL4: SW304.2, SW312.2, SW320.2, SW328.2; also elsewhere on the board
/KYBD_UNiT/KCOL5: SW305.2, SW313.2, SW321.2, SW329.2; also elsewhere on the board
/KYBD_UNiT/KCOL6: SW306.2, SW314.2, SW322.2, SW330.2; also elsewhere on the board
/KYBD_UNiT/KCOL7: SW307.2, SW315.2, SW323.2, SW331.2; also elsewhere on the board
/KYBD_UNiT/KCOL8: SW308.2, SW316.2, SW324.2, SW332.2; also elsewhere on the board
/KYBD_UNiT/KROW1: D201.2 (A), D202.2 (A), D203.2 (A), D204.2 (A), D205.2 (A), D206.2 (A), D207.2 (A), D208.2 (A); also elsewhere on the board
/KYBD_UNiT/KROW2: D209.2 (A), D210.2 (A), D211.2 (A), D212.2 (A), D213.2 (A), D214.2 (A), D215.2 (A), D216.2 (A); also elsewhere on the board
/KYBD_UNiT/KROW3: D217.2 (A), D218.2 (A), D219.2 (A), D220.2 (A), D221.2 (A), D222.2 (A), D223.2 (A), D224.2 (A); also elsewhere on the board
/KYBD_UNiT/KROW4: D225.2 (A), D226.2 (A), D227.2 (A), D228.2 (A), D229.2 (A), D230.2 (A), D231.2 (A), D232.2 (A); also elsewhere on the board
/KYBD_UNiT/ROW1: R341.2; also elsewhere on the board
/KYBD_UNiT/ROW2: R342.2; also elsewhere on the board
/KYBD_UNiT/ROW3: R343.2; also elsewhere on the board
/KYBD_UNiT/ROW4: R344.2; also elsewhere on the board
GND: Q301.2 (E), Q302.2 (E), Q303.2 (E), Q304.2 (E), Q305.2 (E), Q306.2 (E), Q307.2 (E), Q308.2 (E); also elsewhere on the board
unnamed: D201.1 (K), SW301.1
unnamed: D202.1 (K), SW302.1
unnamed: D203.1 (K), SW303.1
unnamed: D204.1 (K), SW304.1
unnamed: D205.1 (K), SW305.1
unnamed: D206.1 (K), SW306.1
unnamed: D207.1 (K), SW307.1
unnamed: D208.1 (K), SW308.1
unnamed: D209.1 (K), SW309.1
unnamed: D210.1 (K), SW310.1
unnamed: D211.1 (K), SW311.1
unnamed: D212.1 (K), SW312.1
unnamed: D213.1 (K), SW313.1
unnamed: D214.1 (K), SW314.1
unnamed: D215.1 (K), SW315.1
unnamed: D216.1 (K), SW316.1
unnamed: D217.1 (K), SW317.1
unnamed: D218.1 (K), SW318.1
unnamed: D219.1 (K), SW319.1
unnamed: D220.1 (K), SW320.1
unnamed: D221.1 (K), SW321.1
unnamed: D222.1 (K), SW322.1
unnamed: D223.1 (K), SW323.1
unnamed: D224.1 (K), SW324.1
unnamed: D225.1 (K), SW325.1
unnamed: D226.1 (K), SW326.1
unnamed: D227.1 (K), SW327.1
unnamed: D228.1 (K), SW328.1
unnamed: D229.1 (K), SW329.1
unnamed: D230.1 (K), SW330.1
unnamed: D231.1 (K), SW331.1
unnamed: D232.1 (K), SW332.1
unnamed: Q301.1 (B), R333.2
unnamed: Q301.3 (C), SW301.5, SW309.5, SW317.5, SW325.5
unnamed: Q302.1 (B), R334.2
unnamed: Q302.3 (C), SW302.5, SW310.5, SW318.5, SW326.5
unnamed: Q303.1 (B), R335.2
unnamed: Q303.3 (C), SW303.5, SW311.5, SW319.5, SW327.5
unnamed: Q304.1 (B), R336.2
unnamed: Q304.3 (C), SW304.5, SW312.5, SW320.5, SW328.5
unnamed: Q305.1 (B), R337.2
unnamed: Q305.3 (C), SW305.5, SW313.5, SW321.5, SW329.5
unnamed: Q306.1 (B), R338.2
unnamed: Q306.3 (C), SW306.5, SW314.5, SW322.5, SW330.5
unnamed: Q307.1 (B), R339.2
unnamed: Q307.3 (C), SW307.5, SW315.5, SW323.5, SW331.5
unnamed: Q308.1 (B), R340.2
unnamed: Q308.3 (C), SW308.5, SW316.5, SW324.5, SW332.5
unnamed: Q309.1 (B), R341.1
unnamed: Q309.2 (E), R301.1, R302.1, R303.1, R304.1, R305.1, R306.1, R307.1, R308.1
unnamed: Q310.1 (B), R342.1
unnamed: Q310.2 (E), R309.1, R310.1, R311.1, R312.1, R313.1, R314.1, R315.1, R316.1
unnamed: Q311.1 (B), R343.1
unnamed: Q311.2 (E), R317.1, R318.1, R319.1, R320.1, R321.1, R322.1, R323.1, R324.1
unnamed: Q312.1 (B), R344.1
unnamed: Q312.2 (E), R325.1, R326.1, R327.1, R328.1, R329.1, R330.1, R331.1, R332.1
unnamed: R301.2, SW301.4
unnamed: R302.2, SW302.4
unnamed: R303.2, SW303.4
unnamed: R304.2, SW304.4
unnamed: R305.2, SW305.4
unnamed: R306.2, SW306.4
unnamed: R307.2, SW307.4
unnamed: R308.2, SW308.4
unnamed: R309.2, SW309.4
unnamed: R310.2, SW310.4
unnamed: R311.2, SW311.4
unnamed: R312.2, SW312.4
unnamed: R313.2, SW313.4
unnamed: R314.2, SW314.4
unnamed: R315.2, SW315.4
unnamed: R316.2, SW316.4
unnamed: R317.2, SW317.4
unnamed: R318.2, SW318.4
unnamed: R319.2, SW319.4
unnamed: R320.2, SW320.4
unnamed: R321.2, SW321.4
unnamed: R322.2, SW322.4
unnamed: R323.2, SW323.4
unnamed: R324.2, SW324.4
unnamed: R325.2, SW325.4
unnamed: R326.2, SW326.4
unnamed: R327.2, SW327.4
unnamed: R328.2, SW328.4
unnamed: R329.2, SW329.4
unnamed: R330.2, SW330.4
unnamed: R331.2, SW331.4
unnamed: R332.2, SW332.4

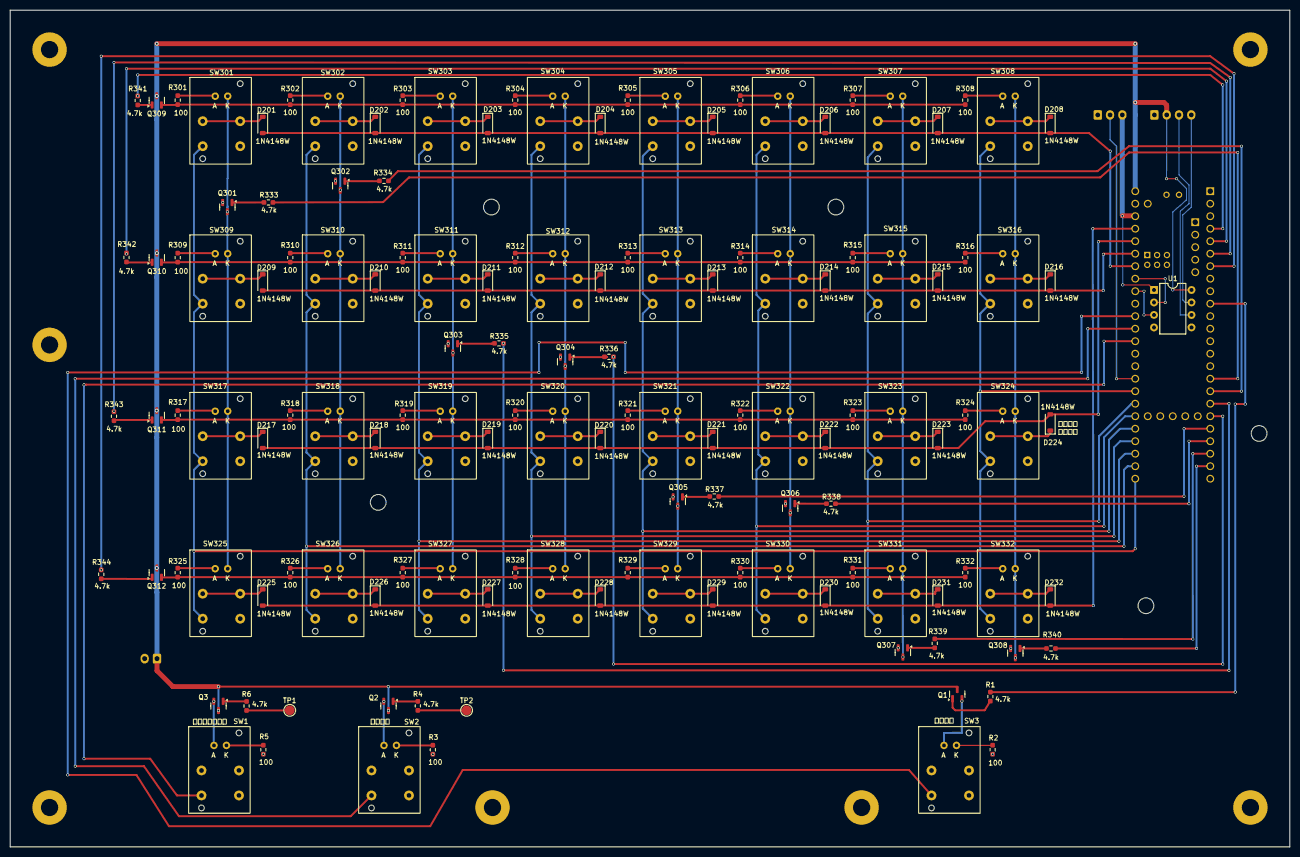
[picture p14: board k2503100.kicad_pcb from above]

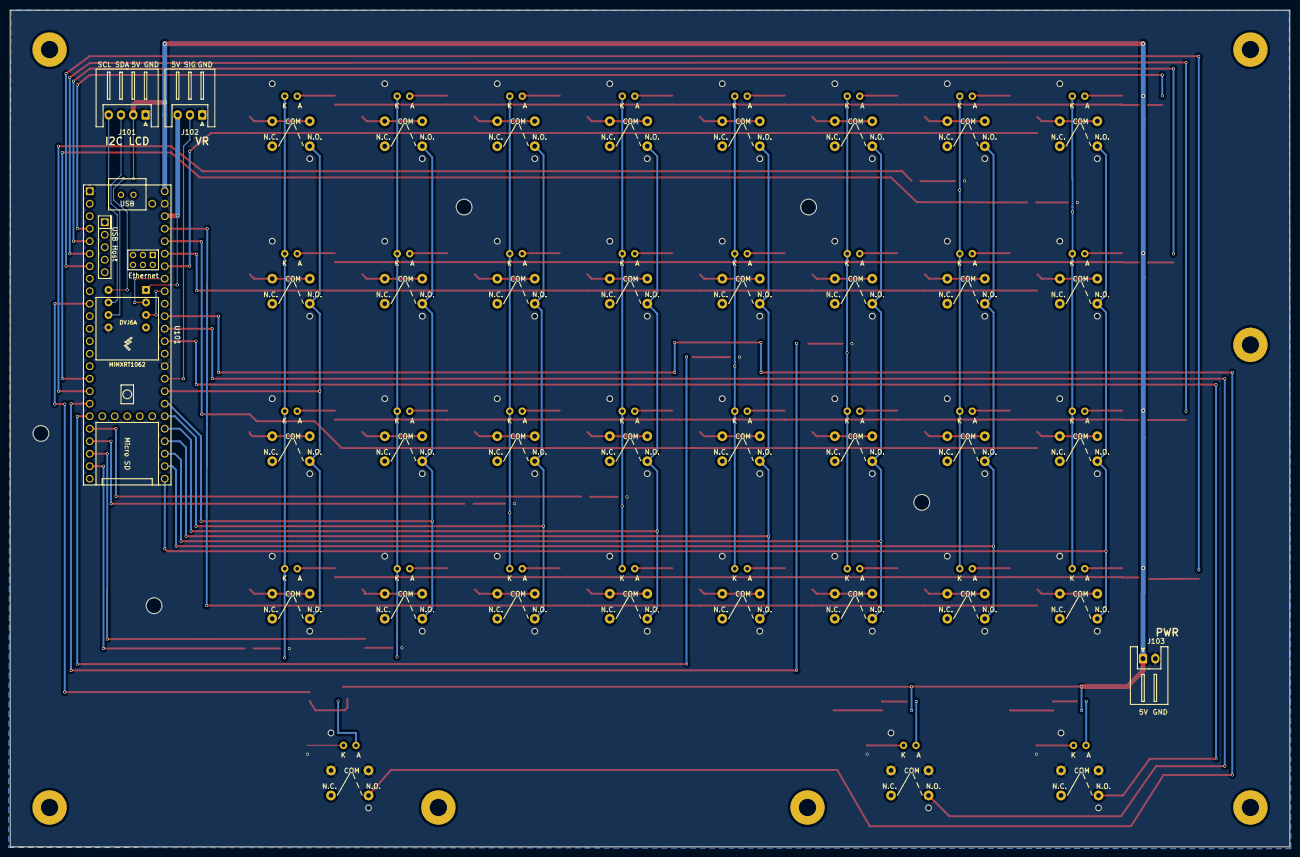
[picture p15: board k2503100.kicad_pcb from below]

Board: 2 copper layers, 260.0 x 170.0 mm, 139 parts (4 on the bottom side), 135 nets.

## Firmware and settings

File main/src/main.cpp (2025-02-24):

#include <Arduino.h>
#include <Wire.h> 
#include <SPI.h>
#include <NativeEthernet.h>
#include <NativeEthernetUdp.h>
#include <LiquidCrystal_I2C.h>
#include "k2503100.h"

#define TIMER_INTERRUPT_DEBUG         0
#define _TIMERINTERRUPT_LOGLEVEL_     0

#include "TeensyTimerInterrupt.h"

// To be included only in main(), .ino with setup() to avoid `Multiple Definitions` Linker Error
#include "Teensy_ISR_Timer.h"


// You can select Teensy Hardware Timer  from TEENSY_TIMER_1 or TEENSY_TIMER_3
// Init Teensy timer TEENSY_TIMER_1
TeensyTimer ITimer(TEENSY_TIMER_1);
// Init Teensy_ISR_Timer
// Each Teensy_ISR_Timer can service 16 different ISR-based timers
Teensy_ISR_Timer ISR_Timer;

LiquidCrystal_I2C lcd(0x27,16,2);  // set the LCD address to 0x27 for a 16 chars and 2 line display
EthernetUDP udp;

volatile bool sirentest_flag,emgstop_flag,broadcast_flag;
volatile bool t1,t1t,t2,t3,bt;
volatile int  c,r;
int p1=0,p2=0,p3=0;
int lc=1 ;
int a17vr,a17pvr;
int sirenTimer,voiceTimer,mailTimer,autoClearTimer;
int psw;
int led[8][4] = {};


void TimerHandler()
{
  ISR_Timer.run();
}

void doingSomething1(void) {
    void sendSnmpSet(IPAddress,const char *,int,char *,const int,const char *);
    void LCDPrint1Line(int,const char *);
    extern const char *rlyoff;
    extern const char *oidbase;
    extern int psw;

    if (sirenTimer>0) {
        if (sirenTimer==1) {
            sendSnmpSet(NDIOTR,oidbase,SirenTEST,rlyoff,snmpPort,community);
            LCDPrint1Line(1," ");
            if (!broadcast_flag) {
                psw = STS0;
            }
        }
        sirenTimer--;
    } else {
        sirenTimer=0;
    }
    if (mailTimer>0) {
        mailTimer--;
    }
    if (voiceTimer>0) {
        voiceTimer--;
    }
    if (autoClearTimer>0) {
        autoClearTimer--;
    }
    lcd.setCursor(15,0);
    lcd.print(psw);
}

void doingSomething3(void) {
    Serial.println("3sec");
}

//void cyclic1s() {
//
//}

void cyclic() {
    int lr,lc,k;
    digitalWrite(LED_BUILTIN,0);
    for (lr=0;lr<4;lr++) {
        digitalWrite((lr+ROW1),1);
        for (lc=0;lc<8;lc++) {
            digitalWrite((lc+COL1),led[lc][lr]);
//            digitalWrite((lc+COL1),1);
        }
        delayMicroseconds(200);
        k = ~k;
        digitalWrite((lr+ROW1),0);
    }
    digitalWrite(LED_BUILTIN,1);
}

void bufprt(void) {
    char tbuf[80];
    Serial.begin(115200);

    for (r=0;r<4;r++) {
        sprintf(tbuf,"%d %d %d %d %d %d %d %d",led[0][r],led[1][r],led[2][r],led[3][r],
                    led[4][r],led[5][r],led[6][r],led[7][r]);
        Serial.println(tbuf);
    }
}

const char *ver = "V0.16";
// Enter a MAC address for your controller below.
// Newer Ethernet shields have a MAC address printed on a sticker on the shield

void setup(void) {
    //char tbuf[80];
    bool stopflag = False;
    int t1,t2,t3;
    extern void pushsw1(void),pushsw2(void),pushsw3(void),LCDPrint1Line(int,const char *);
    extern void setPinMode(void);
    extern void sirentest(void),emgstop(void),broadcast(void);

    c = 0;
    r = 0;
    t1t = True;

    Serial.begin(115200);
    setPinMode();
    digitalWrite(LED_BROADCAST,LOW);

    // LCD初期化
    lcd.init();
    lcd.backlight();
    lcd.setCursor(0,0);
    lcd.print(ver);

    // Ethernet初期化
    Serial.println("Initialize Ethernet");
    LCDPrint1Line(1,"INIT NET");
    Ethernet.init();
    Ethernet.begin(mac,ip,gateway,gateway,netmask);
    //
    // Ethernetの接続エラーに関して書く
    //
    // no point in carrying on, so do nothing forevermore:
    //
    stopflag = False;
    while (stopflag) {
        delay(1);
    }

    // print your local IP address:
    Serial.print("My IP address: ");
    Serial.println(Ethernet.localIP());
    // UDP/SNMPの初期化
    udp.begin(9988);

    bt = False;
    digitalWrite(KROW1,LOW);
    digitalWrite(KROW2,LOW);
    digitalWrite(KROW3,LOW);
    digitalWrite(KROW4,LOW);
    
    Serial.println(ver);
    bufprt();
    attachInterrupt(digitalPinToInterrupt(button_SIRENTEST),sirentest,FALLING);
    attachInterrupt(digitalPinToInterrupt(button_EMGSTOP),emgstop,FALLING);
    attachInterrupt(digitalPinToInterrupt(button_BROADCAST),broadcast,FALLING);
// Interval in microsecs
    if (ITimer.attachInterruptInterval(HW_TIMER_INTERVAL_MS * 1000, TimerHandler)) {
        Serial.print(F("Starting ITimer OK, millis() = ")); Serial.println(millis());
    } else {
        Serial.println(F("Can't set ITimer. Select another freq. or timer"));
    }
    // Just to demonstrate, don't use too many ISR Timers if not absolutely necessary
    // You can use up to 16 timer for each ISR_Timer
    ISR_Timer.setInterval(TIMER_INTERVAL_1S,  doingSomething1);
    //ISR_Timer.setInterval(TIMER_INTERVAL_2S,  doingSomething2);
    //ISR_Timer.setInterval(TIMER_INTERVAL_3S,  doingSomething3);
    ISR_Timer.setInterval(TIMER_INTERVAL_0_01S,cyclic);  // 10mSec Interval
    //ISR_Timer.setInterval(TIMER_INTERVAL_1S,cyclic1s);
    lcd.print(ver);
    sirenTimer = 0;
    voiceTimer = 0;
    mailTimer = 0;
    autoClearTimer = 0;
    psw = STS0;
}

int chkcols(int r) {
    int v;
    delay(50);
    for(v=0;v<8;v++) {
        if (digitalRead(v+33)==HIGH) {
            bt = True;
            return(v+1);
        }
    }
    bt = False;
    return(0);
}
void loop(void) {
    int lc,lr,idx;
    void sendSnmpSet(IPAddress,const char *,int,char *,const int,const char *);
    extern void LCDPrint1Line(int,const char *);
    extern const char *rlyoff, *rlyon;
    extern const char *oidbase;
    extern void dhcpmnt(void);

    r++;
    if (r>4) r=1;
    digitalWrite(KROW1,LOW);
    digitalWrite(KROW2,LOW);
    digitalWrite(KROW3,LOW);
    digitalWrite(KROW4,LOW);
    a17vr = analogRead(VR);
    switch(r) {
        case 1:
            digitalWrite(KROW1,HIGH);
            c = chkcols(r);
            break;
        case 2:
            digitalWrite(KROW2,HIGH);
            c = chkcols(r);
            break;
        case 3:
            digitalWrite(KROW3,HIGH);
            c = chkcols(r);
            break;
        case 4:
            digitalWrite(KROW4,HIGH);
            c = chkcols(r);
            break;
    }
    if (psw==STS0) {
        if (sirentest_flag) {
            sirentest_flag = False;
            Serial.println("Siren Test");
            LCDPrint1Line(1,"SIREN TEST");
            if (sirenTimer==0) {
                sendSnmpSet(NDIOTR,oidbase,SirenTEST,rlyon,snmpPort,community);
                sirenTimer = 3;
                psw = STS2;
            } else {
                sirenTimer = 0;
            }
        }
    }
    if (emgstop_flag) {
        emgstop_flag = False;
        Serial.println("EMERGENCY STOP");
        LCDPrint1Line(1,"EMERGENCY STOP");
        psw = STS0;
        sirentest_flag = False;
        broadcast_flag = False;
        for(lc=0;lc<8;lc++) {
            for (int lr=0;lr<4;lr++) {
                led[lc][lr] = 0;
            }
        }
        digitalWrite(LED_BROADCAST,LOW);
        sirenTimer = 0;

        for(int x=1;x<=MailCH32;x++) {
            sendSnmpSet(NDIOTR,oidbase,x,rlyoff,snmpPort,community);
            delay(10);
        }
        sendSnmpSet(NDIOTR,oidbase,EMG_STOP,rlyon,snmpPort,community);
        delay(1000);
        sendSnmpSet(NDIOTR,oidbase,EMG_STOP,rlyoff,snmpPort,community);
        psw = STS0;
        LCDPrint1Line(1," ");
    }
    if (broadcast_flag) {
        if (psw==STS1) {
            Serial.println("Broadcast siren");
            LCDPrint1Line(1,"BROADCAST SIREN");
            for(lc=0;lc<8;lc++) {
                for(lr=0;lr<4;lr++) {
                    idx = lc + (lr*8);
                    if (led[lc][lr]==1) {
                        sendSnmpSet(NDIOTR,oidbase,SirenCH01+idx,rlyon,snmpPort,community);
                    } else {
                        sendSnmpSet(NDIOTR,oidbase,SirenCH01+idx,rlyoff,snmpPort,community);
                    }
                }
            }
            sirenTimer = 5;
            psw = STS2;
            digitalWrite(LED_BROADCAST,HIGH);
        } else if (psw==STS2) {
            if (sirenTimer==0) {
                psw = STS3;
                // Stop siren
                for(idx=1;idx<=SirenCH32;idx++) {
                    sendSnmpSet(NDIOTR,oidbase,idx,rlyoff,snmpPort,community);
                    delay(10);
                }
                LCDPrint1Line(1,"VOICE AND MAIL");
                for (lc=0;lc<8;lc++) {
                    for (lr=0;lr<4;lr++) {
                        if (led[lc][lr]==1) {
                            sendSnmpSet(NDIOTR,oidbase,VoiceCH01+(lc+(lr*8)),rlyon,snmpPort,community);
                            delay(10);
                            sendSnmpSet(NDIOTR,oidbase,MailCH01+(lc+(lr*8)),rlyon,snmpPort,community);
                            delay(10);
                        } else {
                            sendSnmpSet(NDIOTR,oidbase,VoiceCH01+(lc+(lr*8)),rlyoff,snmpPort,community);
                            delay(10);
                            sendSnmpSet(NDIOTR,oidbase,MailCH01+(lc+(lr*8)),rlyoff,snmpPort,community);
                            delay(10);
                        }
                    }
                }
                mailTimer = 3;
                voiceTimer = 60;
            }
        } else if (psw==STS3) {
            if (mailTimer==0) {
                for (idx=0;idx<32;idx++) {
                    sendSnmpSet(NDIOTR,oidbase,MailCH01+idx,rlyoff,snmpPort,community);
                    delay(10);
                }
                LCDPrint1Line(1,"VOICE");
                mailTimer = 0;
                psw = STS3v;
            }
        } else if (psw==STS3v) {
            if (voiceTimer==0) {
                for (idx=0;idx<32;idx++) {
                    sendSnmpSet(NDIOTR,oidbase,VoiceCH01+idx,rlyoff,snmpPort,community);
                    delay(10);
                }
                for(lc=0;lc<8;lc++) {
                    for(lr=0;lr<4;lr++) {
                        led[lc][lr]=0;
                    }
                }   
                LCDPrint1Line(1,"END");
                mailTimer = 0;
                psw = STS0;
                broadcast_flag = False;
                digitalWrite(LED_BROADCAST,LOW);
            }
        }
    }
    if (bt) {
        led[c-1][r-1] = (led[c-1][r-1]==0)? 1:0;
        //Serial.print("CR=");
        //Serial.print(c);
        //Serial.print("x");
        //Serial.println(r);
        bt = False;
        // check led status
        int z = 0;
        for (lc=0;lc<8;lc++) {
            for (lr=0;lr<4;lr++) {
                z += led[lc][lr];
            }
            if (z>0) {
                psw=STS1;
                autoClearTimer = 60;
                sirentest_flag=False;
            } else {
                psw=STS0;
                sirentest_flag=False;
            }
        }
    }
    if (psw==STS1) {
        if (autoClearTimer==0) {
            for (lc=0;lc<8;lc++) {
                for (lr=0;lr<4;lr++) {
                    led[lc][lr] = 0;
                }
            }
            broadcast_flag = False;
            psw = STS0;
        }
    }
    // Check VR value
    if (a17vr!=a17pvr) {
        a17pvr = a17vr;
    }
}

void dhcpmnt(void) {
    return;
    switch (Ethernet.maintain()) {
    case 1:
        //renewed fail
        Serial.println("Error: renewed fail");
        break;
    case 2:
        //renewed success
        Serial.println("Renewed success");
        //print your local IP address:
        Serial.print("My IP address: ");
        Serial.println(Ethernet.localIP());
        break;
    case 3:
        //rebind fail
        Serial.println("Error: rebind fail");
        break;
    case 4:
        //rebind success
        Serial.println("Rebind success");
        //print your local IP address:
        Serial.print("My IP address: ");
        Serial.println(Ethernet.localIP());
        break;
    default:
        //nothing happened
        break;
    }
}

void LCDPrint1Line(int l,const char *str) {
    lcd.setCursor(0,l);
    lcd.print("                   ");
    lcd.setCursor(0,l);
    lcd.print(str);
}
 
void sirentest(void) {
    delay(5);
    int s1 = digitalRead(button_SIRENTEST);
    if (s1==sirentest_flag) sirentest_flag = 1;
}

void emgstop(void) {
    delay(5);
    int s2 = digitalRead(button_EMGSTOP);
    if (s2==emgstop_flag) emgstop_flag = 1;
}

void broadcast(void) {
    delay(5);
    int s2 = digitalRead(button_BROADCAST);
    if (s2==broadcast_flag) broadcast_flag = 1;
}

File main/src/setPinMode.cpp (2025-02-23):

#include <Arduino.h>
#include "pin_io.h"

void setPinMode(void) {
    pinMode(VR,INPUT);
    pinMode(button_SIRENTEST,INPUT_PULLUP);
    pinMode(button_EMGSTOP,INPUT_PULLUP);
    pinMode(button_BROADCAST,INPUT_PULLUP);
    pinMode(KROW1,OUTPUT);
    pinMode(KROW2,OUTPUT);
    pinMode(KROW3,OUTPUT);
    pinMode(KROW4,OUTPUT);
    pinMode(KCOL1,INPUT_PULLDOWN);
    pinMode(KCOL2,INPUT_PULLDOWN);
    pinMode(KCOL3,INPUT_PULLDOWN);
    pinMode(KCOL4,INPUT_PULLDOWN);
    pinMode(KCOL5,INPUT_PULLDOWN);
    pinMode(KCOL6,INPUT_PULLDOWN);
    pinMode(KCOL7,INPUT_PULLDOWN);
    pinMode(KCOL8,INPUT_PULLDOWN);
    pinMode(COL1, OUTPUT);
    pinMode(COL2, OUTPUT);
    pinMode(COL3, OUTPUT);
    pinMode(COL4, OUTPUT);
    pinMode(COL5, OUTPUT);
    pinMode(COL6, OUTPUT);
    pinMode(COL7, OUTPUT);
    pinMode(COL8, OUTPUT);
    pinMode(LED_BROADCAST, OUTPUT);
}

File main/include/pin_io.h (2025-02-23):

#define SW1 14
#define button_SIRENTEST 14
#define SW2 15
#define button_EMGSTOP 15
#define SW3 16
#define button_BROADCAST 16
#define VR  A17
#define COL1  24
#define COL2  25
#define COL3  26
#define COL4  27
#define COL5  28
#define COL6  29
#define COL7  30
#define COL8  31

#define ROW1  2
#define ROW2  3
#define ROW3  4
#define ROW4  5

#define LED_BROADCAST  8

#define KCOL1 33
#define KCOL2 34
#define KCOL3 35
#define KCOL4 36
#define KCOL5 37
#define KCOL6 38
#define KCOL7 39
#define KCOL8 40

#define KROW1 20
#define KROW2 21
#define KROW3 22
#define KROW4 23

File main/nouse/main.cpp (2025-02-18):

#include "k2503100.h"
#include "lib-lcd.h"
#include "lib-snmp.h"
//#include "lib-button.h"

void setup(void) {
    extern void lcd_setup(void);
    extern void button_setup(void);
    extern byte oidbase[];
    extern byte community[];
    extern byte gateway[];
    extern byte NDIOTR[];
    extern byte netmask[];
    extern byte ip[];
    extern byte mac[];
    snmp_setup();    
    lcd_setup();
    button_setup();
    Serial.begin(115200);
    Serial.println("SNMP Set Example for Teensy 4.1 k2503100-11");
    lcd_display(0,0,"k2503100-12");

}

void loop(void) {
  // put your main code here, to run repeatedly:
  digitalWrite(13, HIGH);
  delay(1000);
  digitalWrite(13, LOW);
  delay(1000);
}

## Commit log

2023-09-01 CAD: 1st
    [k2503100.kicad_pcb, k2503100.kicad_sch]
2023-09-15 Keyboard_UNiT記述中
    [Keyboard_UNiT.kicad_sch, Relay_UNiT.kicad_sch, k2503100.kicad_sch]
2023-09-16 途中 Relay Unit
    [Keyboard_UNiT.kicad_sch, Relay_UNiT.kicad_sch, k2503100.kicad_sch]
2023-09-18 Relay_UNiTの端子名入れ途中
    [Relay_UNiT.kicad_sch, k2503100.kicad_sch]
2024-05-18 KiCAD 8
    [Keyboard_UNiT.kicad_sch, Relay_UNiT.kicad_sch]
2024-05-23 設計資料作り
    [01.kicad_pcb, 01.kicad_sch, Keyboard_UNiT.kicad_sch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]
2024-05-24 説明文書構成図で遅延装置無し版を作成DIAGRAM02.pdf
    [01.kicad_sch]
2024-05-24 回路図にとりかかる
    [button.kicad_sch, k2503100snmp.kicad_pcb, k2503100snmp.kicad_sch]
2024-07-02 SNMP and Teensy
2024-07-02 MP86A1のパーツ作成
    [Keyboard.kicad_sch, Keyboard_UNiT.kicad_sch, Relay_UNiT.kicad_sch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]
2024-07-03 KYBD_UNit途中
    [KYBD_UNit.kicad_sch, k2503100.kicad_sch]
2024-08-07 未使用回路の削除
    [KYBD_UNit.kicad_sch, k2503100.kicad_sch]
2024-08-26 KCOL側配線途中
    [KYBD_UNit.kicad_sch, k2503100.kicad_sch]
2024-08-27 KYBD UNIT ほぼ完成
    [KYBD_UNit.kicad_sch, k2503100.kicad_sch]
2024-08-27 CPUとの接続途中
    [KYBD_UNit.kicad_sch, k2503100.kicad_sch]
2024-09-25 DOCS:追加
2024-10-02 PDF作成
    [KYBD_UNit.kicad_sch, k2503100.kicad_sch]
2024-10-04 Teensy tools の追加
2025-01-30 PCBデザイン開始
    [KYBD_UNit.kicad_sch, k2503100.kicad_pcb, k2503100.kicad_sch]
2025-01-31 PCB設計中
    [KYBD_UNit.kicad_sch, k2503100.kicad_pcb, k2503100.kicad_sch]
2025-01-31 マウントホール追加。I2Cなどを追加予定
    [k2503100.kicad_pcb]
2025-02-01 LCDとVRコネクタ追加
    [k2503100.kicad_pcb, k2503100.kicad_sch]
2025-02-01 寸法図途中
    [k2503100.kicad_pcb, k2503100.kicad_sch]
2025-02-02 スタッドを立てる位置はほぼ決まり。
    [k2503100.kicad_pcb]
2025-02-02 ケース加工用寸法線途中
2025-02-02 寸法線記入
    [k2503100.kicad_pcb]
2025-02-02 寸法線作業
    [k2503100.kicad_pcb]
2025-02-03 case設計
2025-02-04 PCB発注とソフト開発
    [KYBD_UNit.kicad_sch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]
2025-02-05 SNMPソフト開発中
2025-02-06 PCB製造開始
    [T-FSA5944W24028G-2sets-B67819ASP31-k2503100-pcbgogo-bom(2025-02-06).xls]
2025-02-07 POSファイル追加
2025-02-10 3DプリンタでRJ-45の留具を作るなど
    [NIC-Adapter2-3views.FCStd, NIC-Adapter2.FCStd, NIC-Adapter2.stl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]
2025-02-16 ソフト製作開始、mainの下でbutton14.cppなどを参考にしてる
2025-02-17 基板試作写真とソースコード編集中
2025-02-22 PCB 1.20まで（含む）は間違いなので使わない
    [k2503100.kicad_pcb]
2025-02-23 プログラム編集中、broadcast_flagの範囲がおかしい
2025-02-24 とりあえず動作確認版
2025-02-24 V0.16 STS1での1分間自動リセットの設定を行う
2025-03-03 ケース用寸法の追加
    [k2503100.kicad_pcb]
2025-03-24 MMBT3904に変更を開始
    [KYBD_UNit.kicad_sch, k2503100.kicad_pcb, k2503100.kicad_sch]
2025-03-25 MMBT3904変更済み
    [KYBD_UNit.kicad_sch, k2503100.kicad_pcb, k2503100.kicad_sch]
